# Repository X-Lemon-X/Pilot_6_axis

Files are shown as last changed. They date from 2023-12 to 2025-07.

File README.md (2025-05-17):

# 6 axis remote Controler
- Works over Wi-Fi ( sends constant length ASCI data frame)
- Up to 6 networks saved (with priority from  1 to 6)
- All settings of the Rc can be changed on a configuration website
- Controled inertia of the joysticks and signal values of the joystick coordinates
- Veriable signal refresh rate up to 200Hz
- Auto zero positioning (no more robots moving in slow speed without touching the pilot)
- USB-C charged!
- two 3-DOF joysticks
- 10 buttons (2 of which are on Joy Sticks)
- Integrated LCD
- The RC remembers settings so no need to set it up every time or reprogram it.

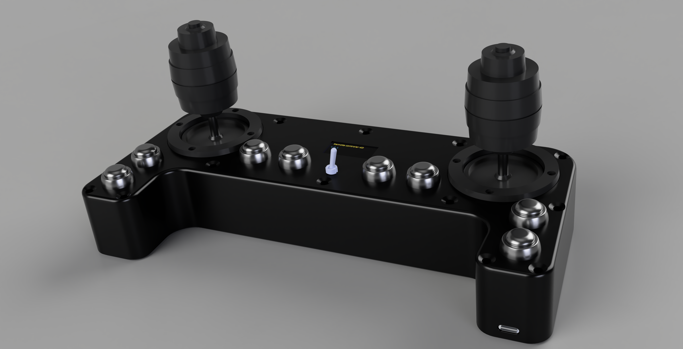
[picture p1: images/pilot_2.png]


## The repo supports demo pc keyboard version of the RC 
 Pc keyboard version for RC without the need for the hardware.
 
 ```bash
  python3 -m venv .venv
  python3 -m pip -r requirements.txt
  source .venv/bin/activate
  python3 pilot_6axis/pilot_6axis/keyboard_rc.py -i IP_ADDRESS -p PORT -f FREQUENCY -v JOYSTICK_VALUE
 ```
for help
```bash
  python3 pilot_6axis/pilot_6axis/keyboard_rc.py
 ```

## To build and run ros package
```bash
  colcon build --packages-select pilot_6axis
  source install/setup.bash 
  ros2 run pilot_6axis rc_node
```

## Data frame
 Consist of 18 elements separated by ':'.
Depending on the settings int_Joystick_(left/right)_(MMin/MMax) value returned by joystick will vary. This setting values should be between -9999<=x<=9999 or 0<=x<=99999 or the data frame length won't be constant, for buttons: 1-pressed 0-not pressed.
```bash
 Example: "$Rc:  340:   200:   12:1:  500:-2045: 2045:1:1:1:0:1:1:0:1:0:#\r"
```

 1. control beginning "$Rc"
 2. joystick_left_x   (5-characters) 
 3. joystick_left_y   (5-characters)
 4. joystick_left_z   (5-characters)
 5. joystick_left_btn  (1-character)
 6. joystick_right_x   (5-characters)
 7. joystick_right_y   (5-characters)
 8. joystick_right_z   (5-characters)
 9. joystick_right_btn  (1-character)
 10. btn_1  (1-character)
 11. btn_2  (1-character)
 12. btn_3  (1-character)
 13. btn_4  (1-character)
 14. btn_5  (1-character)
 15. btn_6  (1-character)
 16. btn_7  (1-character)
 17. btn_8  (1-character)
 18. control end "#\r"

## How to use
### Setup
  1. Enable setup mode by pressing and holding the most centeral button 4 or 5 when turning the Rc On (doesn't matter which one).
  2. Connect to the Rc Wi-Fi network that is displayed on  the LCD.
  3. Open web browser and go to url displayed on the LCD.
  4. Set up the settings of the Rc and press save buttons on the bottom of the page. This will redirect you to the page where you will see if settings were saved. If you made some error it will be shown here.
  5. To leave setup mode shut down the Rc and turn it on again.
  6. Now the Rc will connect to the network with the highest priority that is available. If it can't connect to any of the saved networks it will keep trying to connect to them. If the Rc is connected to the network it will display the IP address on the LCD and show Connected status.
  7. Now setup is done and you can use the Rc.
## Settings list:
#### General Settings
  - **Joystick left MMin** -> minimum value of the left joystick x, y, z axis on the min of the range 
  - **Joystick left MMax** -> maximum value of the left joystick x, y, z axis on the max of the range
  - **Joystick left filer** -> inertia of the left joystick (0-1), the higher inertia the response of the joystick value will be faster.
  - **Joystick right MMin** -> minimum value of the right joystick x, y, z axis on the min of the range
  - **Joystick right MMax** -> maximum value of the right joystick x, y, z axis on the max of the range
  - **Joystick right filer** -> inertia of the right joystick (0-1)
  - **WIFI SSID** => SSID of the wifi network created by the RC in setup mode.
  - **WIFI PASSWORD** => password of the wifi network made by the RC in setup mode
  - **Update frequency** => frequency of sending data frame
  - **Target IP** => IP address to which the RC will send data frame
  - **Host Port** => port to which the RC will send data frame

#### WIFI target networks
  - **Wifi [number 1-6] : Seed** => SSID of the wifi network (where number means priority from 1 to 6)
  - **Wifi [number 1-6] : Password** => Password of the wifi network

## Required component list

### Component Images

  | Component | Photo | Component | Photo |
  |-----------|-------|-----------|-------|
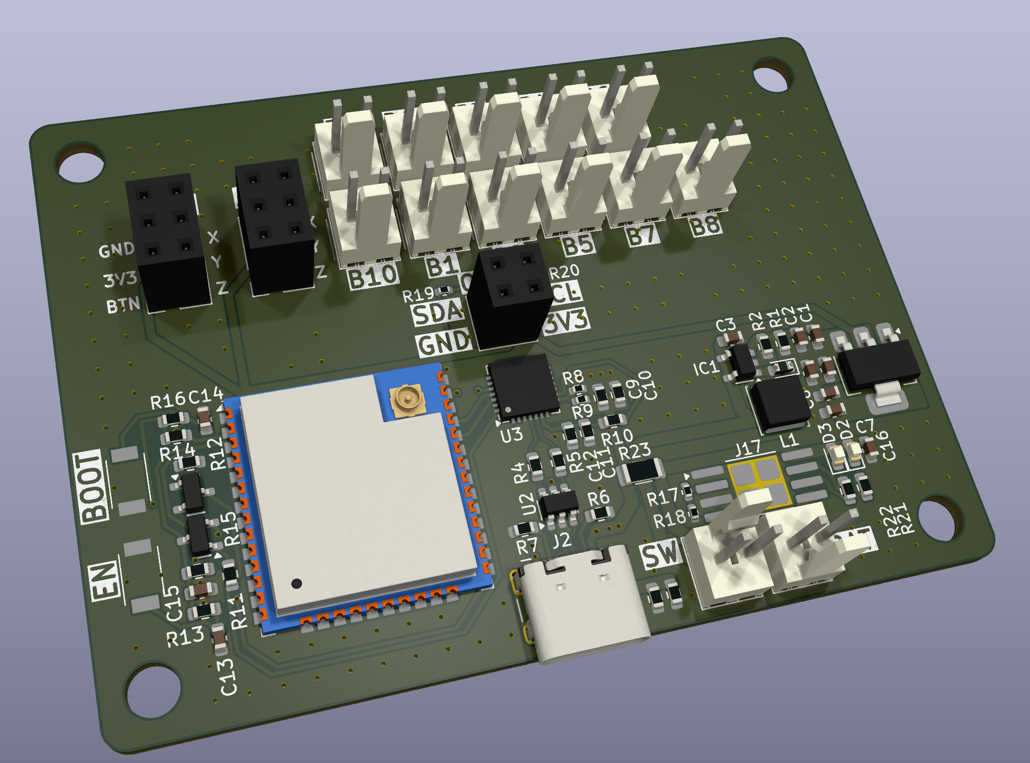
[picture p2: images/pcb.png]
PCB
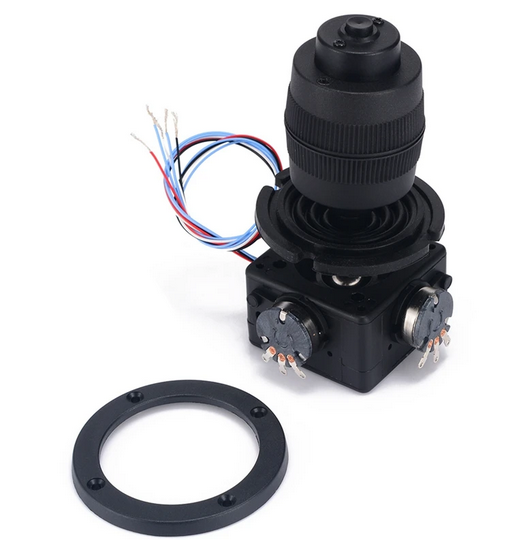
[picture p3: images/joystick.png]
Joystick
  | PCB (order from JLCPCB) |  | Joystick 4-axis JH-D400B-M4 |  |
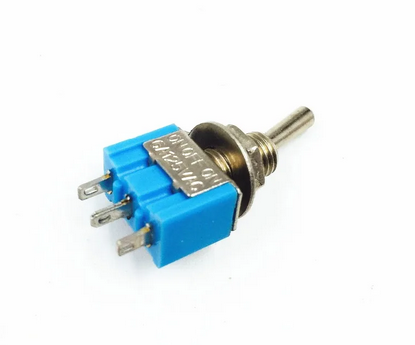
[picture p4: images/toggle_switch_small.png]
Toggle switch
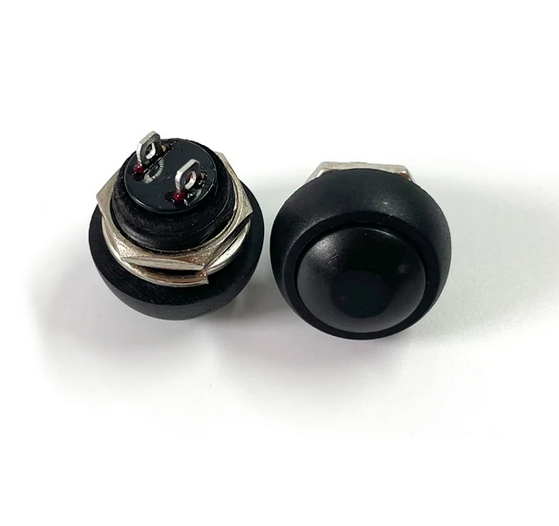
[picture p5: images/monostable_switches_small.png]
Monostable switches
  | Toggle switch 6mm MTS-103 |  | Monostable switches 12mm PBS-33B |  |
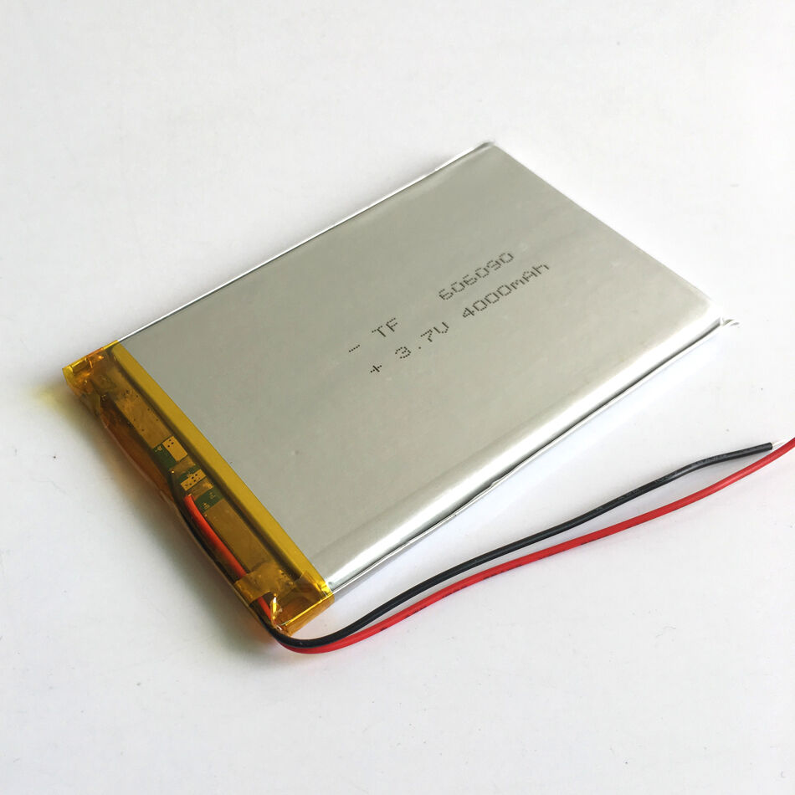
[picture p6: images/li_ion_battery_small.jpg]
Li-ion battery
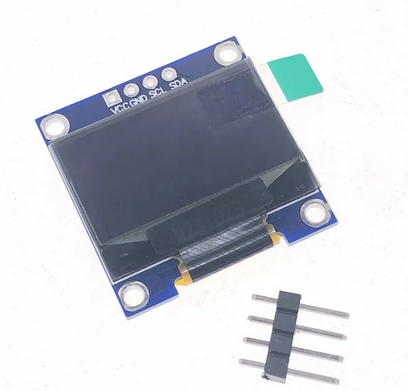
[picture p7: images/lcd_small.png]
LCD
  | Li-ion battery 3.7V 4000mAh |  | LCD 1.3" 128x64 OLED SSD1306 |  |
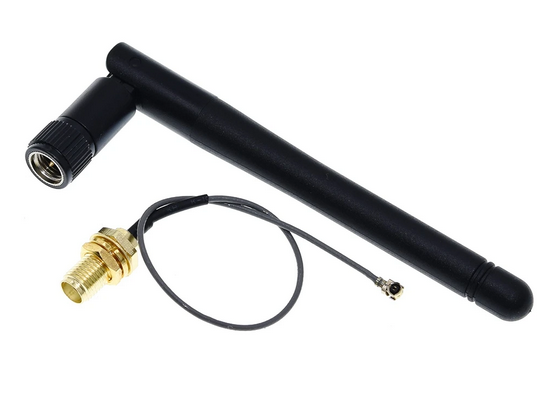
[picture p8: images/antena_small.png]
Antenna
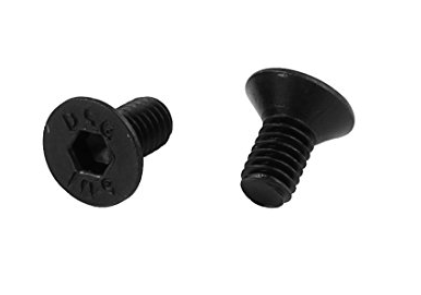
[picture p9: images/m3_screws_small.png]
M3 screws
  | Antena 2.4GHz 3dBi WiFi RP-SMA |  | M3 6mm hex socket flat countersunk |  |
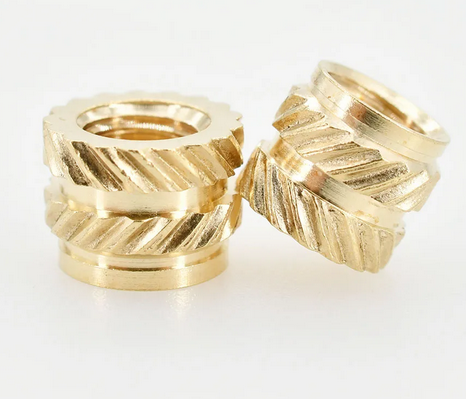
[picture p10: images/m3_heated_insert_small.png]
M3 heated insert
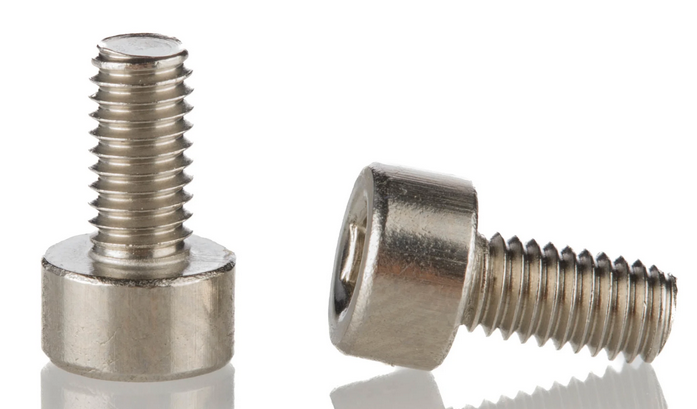
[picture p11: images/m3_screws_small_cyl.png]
M3 screws cylindrical
  | M3 heated insert M3xL3xOD4.2 |  | M3 5mm hex socket cylindrical |  |

### Component list 

  | Component Name                                   | Parts Count | Description                                              |
  |--------------------------------------------------|-------------|----------------------------------------------------------|
  | Joystick 4-axis JH-D400B-M4                      | 2           | 3-DOF joysticks for axis control                        |
  | Toggle switch 6mm MTS-103                        | 1           | Main toggle switch for power or mode selection           |
  | Monostable switches 12mm PBS-33B                 | 8           | Momentary push buttons for user input                   |
  | Li-ion battery 606090 3.7V 4000mAh               | 1           | Rechargeable battery for power supply                    |
  | LCD 1.3" 128x64 OLED SSD1306                     | 1           | Display for status and configuration                     |
  | Antena 2.4GHz 3dB WiFi 2.4GHz RP-SMA             | 1           | External Wi-Fi antenna for wireless communication        |
  | M3 6mm hex socket flat countersunk screws        | 14          | Screws for assembling the enclosure                      |
  | M3 heated insert M3xL3xOD4.2                     | 19          | Threaded inserts for secure screw mounting               |
  | M3 5mm hex socket cylindrical screws             | 4           | Additional screws for assembly                           |
  | PCB (order from JLCPCB)                          | 1           | Main circuit board for the controller                    |
  | BOM Components (see BOM file)                    | -           | All other electronic components (resistors, ICs, etc.)   |

- BOM file "Electric schematic/Pilot6Axis/jlcpcb/production_files/BOM-Pilot6Axis.csv"
- JLCB gerber files "Electric schematic/Pilot6Axis/jlcpcb/production_files/GERBER-Pilot6Axis.zip"

## How to assembly
  You figure it out.

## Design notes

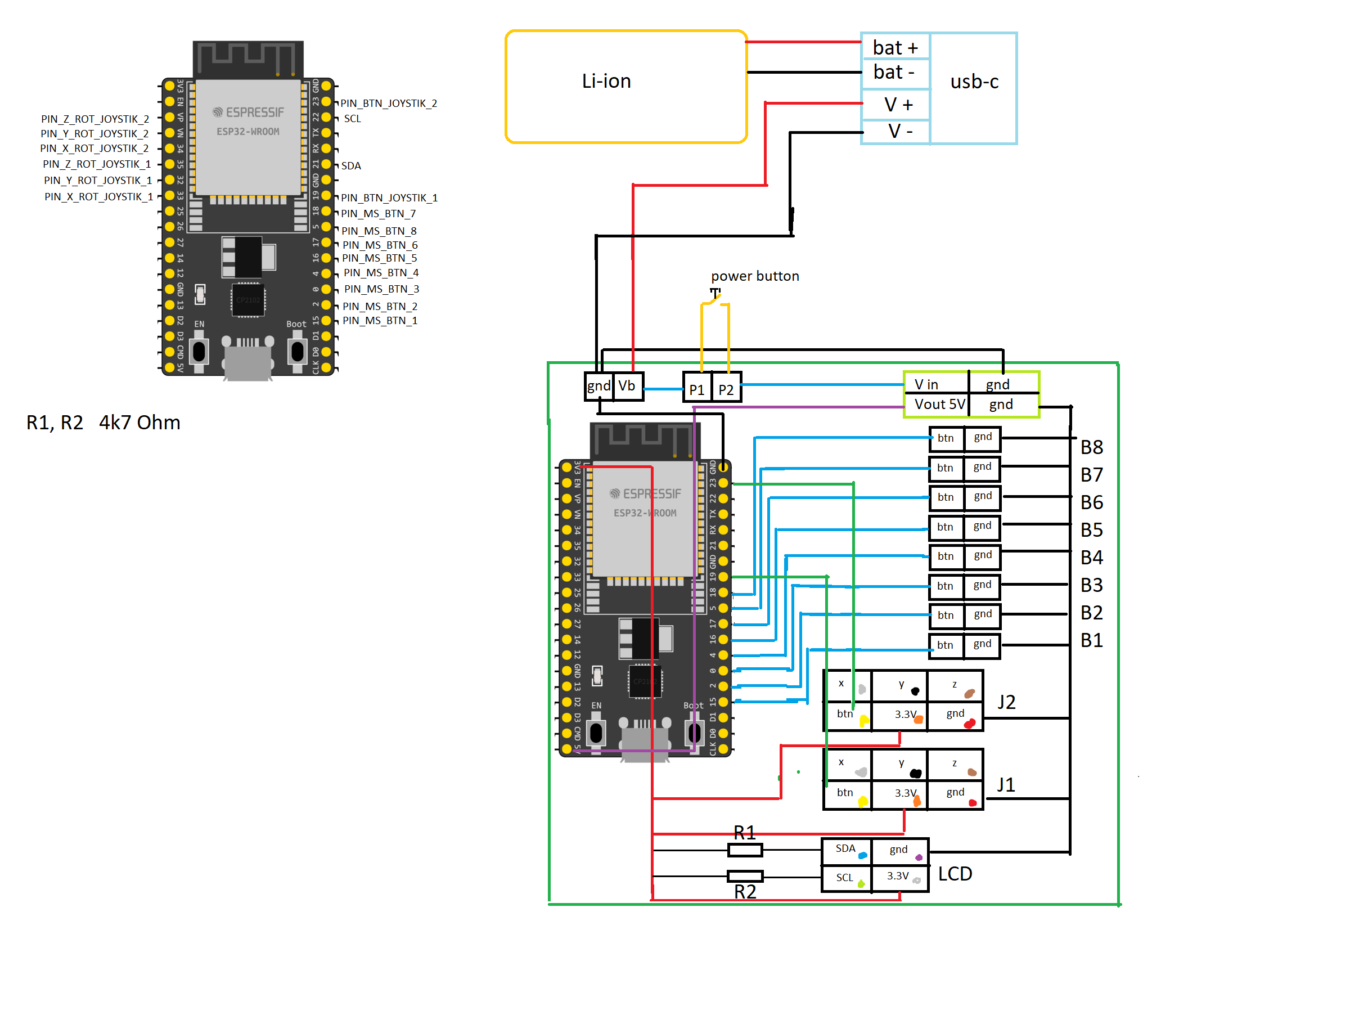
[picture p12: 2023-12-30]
Electric schematic/Pilot 6 axis electronic schematic.png

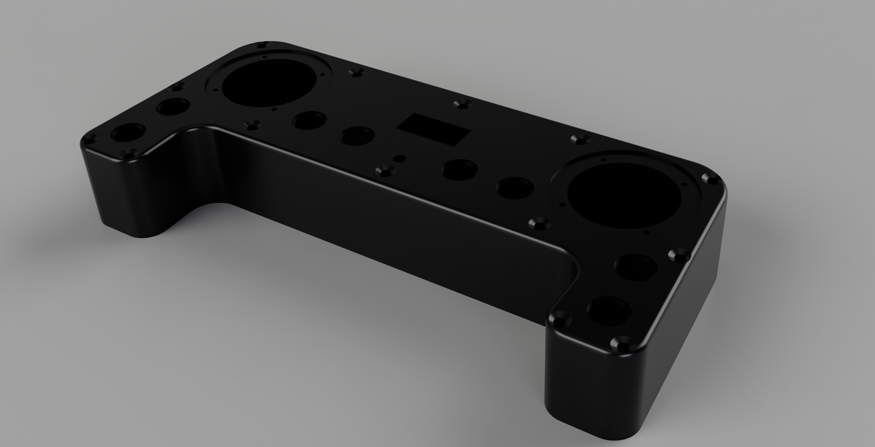
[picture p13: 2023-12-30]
images/pilot_1.png

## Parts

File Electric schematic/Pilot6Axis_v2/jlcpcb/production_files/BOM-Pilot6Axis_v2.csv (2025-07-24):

Comment | Designator | Footprint | LCSC | Quantity
10uH | L1 | L_Cenker_CKCS4018 | C1035 | 1
40.5k | R2 | R_0603_1608Metric | C12447 | 1
100n | C10,C11,C17,C18,C19,C22,C25,C26,C3,C34,C43,C45,C46,C7 | R_0603_1608Metric | C14663 | 14
1k | R10 | R_0603_1608Metric | C14676 | 1
1nF | C13,C14,C35,C36,C47,C5,C6 | C_0603_1608Metric | C1588 | 7
220pF | C23,C24,C4 | C_0603_1608Metric | C1603 | 3
47nF | C27,C28 | C_0603 | C1622 | 2
4.7uF | C1,C16,C39 | C_0603_1608Metric | C19666 | 3
10u | C12,C44,C9 | R_0603_1608Metric | C19702 | 3
S9014 | Q1,Q2 | Q_SOT-23 | C20069130 | 2
AO3400A | Q3,Q4 | Q_SOT-23 | C20917 | 2
1kΩ | R13,R14,R25,R28,R30,R31,R32 | R_0603 | C21190 | 7
100Ω | R26 | R_0603 | C22775 | 1
Red | D2,D3,D4,D5,D6,D7,D8 | D_0603 | C2286 | 7
30kΩ | R22 | R_0603 | C22984 | 1
330Ω | R4 | R_0603 | C23138 | 1
4.7kΩ | R19,R20 | R_0603 | C23162 | 2
22Ω | R29 | R_0603 | C23345 | 1
100kΩ | R1,R24 | R_0603 | C25803 | 2
5.1kΩ | R21 | R_0402 | C25905 | 1
13.3k | R11,R12,R15,R16,R17,R18,R3,R8,R9 | R_0603_1608Metric | C25952 | 9
USB_C_Receptacle_USB2.0_16P | J3 | USB_C_Receptacle_HCTL_HC-TYPE-C-16P-01A | C2765186 | 1
MBR0520 | D1 | D_0603_1608Metric | C2858712 | 1
LM27313XMFX_NOPB | IC1 | SOT-23-5 | C341750 | 1
3kΩ | R27 | R_0603 | C4211 | 1
33k | R5 | R_0603_1608Metric | C4216 | 1
USBLC6-2SC6 | U2 | SOT-23-6 | C5180249 | 1
10nF | C8 | R_0603_1608Metric | C57112 | 1
AMS1117-3.3 | U1 | SOT-223-3_TabPin2 | C6186 | 1
22R | R6,R7 | R_0603_1608Metric | C71618 | 2
10uF | C15,C2,C20,C21,C29,C30,C31,C32,C33,C37,C38,C40,C41,C42 | C_0603 | C96446 | 14
CP2102N-Axx-xQFN28 | U3 | QFN-28-1EP_5x5mm_P0.5mm_EP3.35x3.35mm | C964632 | 1
127k | R23 | R_0603_1608Metric |  | 1
Conn_01x06 | J9 | JST_PH_B6B-PH-K_1x06_P2.00mm_Vertical |  | 1
TPS25751SRSMR | IC2 | QFN40P400X400X100-33N-D |  | 1
SolderJumper_2_Bridged | JP1 | SolderJumper-2_P1.3mm_Open_TrianglePad1.0x1.5mm |  | 1
Conn_01x12 | J8 | JST_PH_B12B-PH-K_1x12_P2.00mm_Vertical |  | 1
Conn_01x06 | J4 | JST_PH_B6B-PH-K_1x06_P2.00mm_Vertical |  | 1
MCP23017_ML | U14 | QFN-28-1EP_6x6mm_P0.65mm_EP4.25x4.25mm |  | 1
10k | TH1 | PinHeader_1x02_P2.54mm_Vertical |  | 1
TPS3422EGDRYR | IC4 | DRY_R-PUSON-N6_ |  | 1
SN74LVC1G74RSE2 | IC5 | SN74LVC1G74RSE2 |  | 1
BQ25792RQMR | IC3 | BQ25792RQMR |  | 1
1u | L2 | L_APV_APH0420 |  | 1
ESP32-WROOM-32U | U4 | ESP32-WROOM-32U |  | 1
Battery input | J1 | JST_PH_B2B-PH-K_1x02_P2.00mm_Vertical |  | 1
Conn_01x06 | J10 | JST_PH_B6B-PH-K_1x06_P2.00mm_Vertical |  | 1
Oled | J6 | PinSocket_2x02_P2.54mm_Vertical |  | 1
~ | U12 | ts-1212f |  | 1
~ | U7 | ts-1212f |  | 1
~ | U9 | ts-1212f |  | 1
Power switch | U18 | ts-1212f |  | 1
~ | U6 | ts-1212f |  | 1
~ | U10 | ts-1212f |  | 1
~ | U11 | ts-1212f |  | 1
~ | U8 | ts-1212f |  | 1
~ | U15 | ts-1212f |  | 1
~ | U13 | ts-1212f |  | 1
~ | U16 | ts-1212f |  | 1
~ | U5 | ts-1212f |  | 1
CAT24C512WI-GT3 | U17 | SOIC-8_3.9x4.9mm_P1.27mm |  | 1

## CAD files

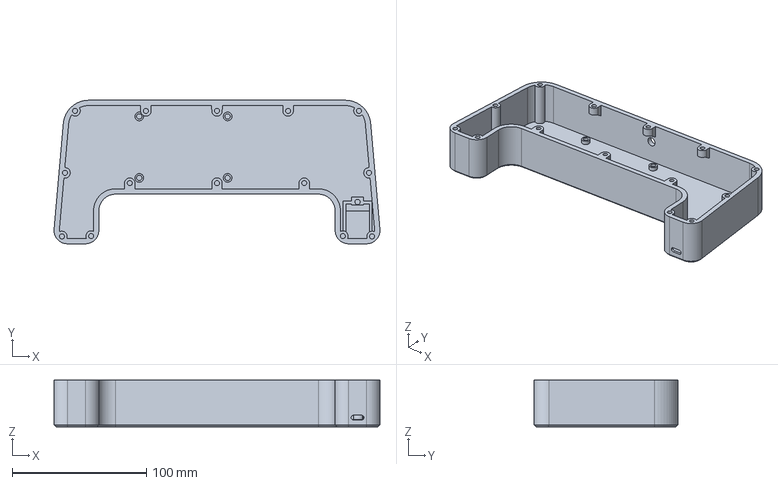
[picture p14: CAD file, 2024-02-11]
3D_Files/Pilot6axisV2.step
242.9 x 107.0 x 35.0 mm

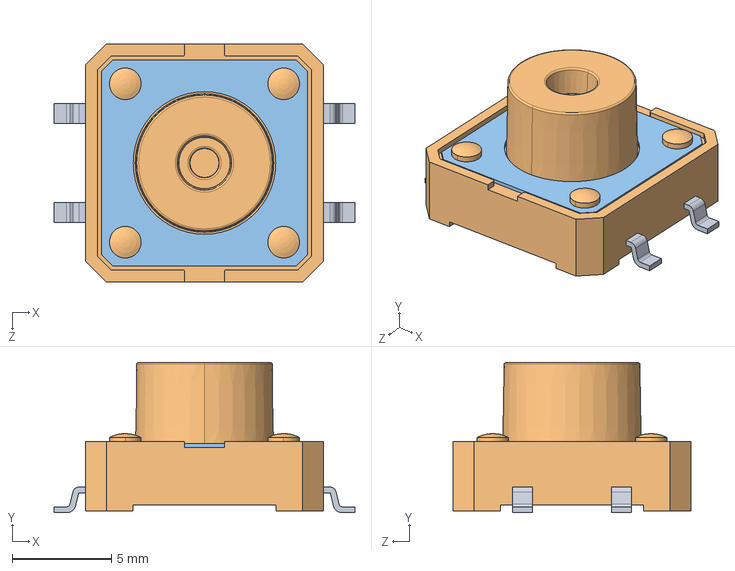
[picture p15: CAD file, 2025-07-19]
Electric schematic/Pilot6Axis_v2/parts/Same_Sky_TS16-1212-75-BK-160-SMT-TR.step
15.2 x 7.60 x 12.0 mm

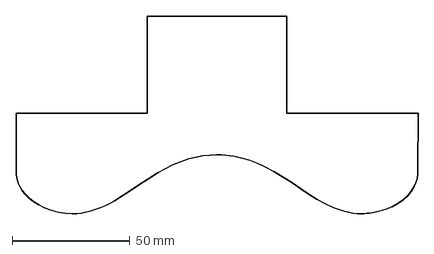
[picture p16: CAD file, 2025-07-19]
Electric schematic/Pilot6Axis_v2/pilot6axis_edge_cuts.dxf
171.0 x 83.9 mm

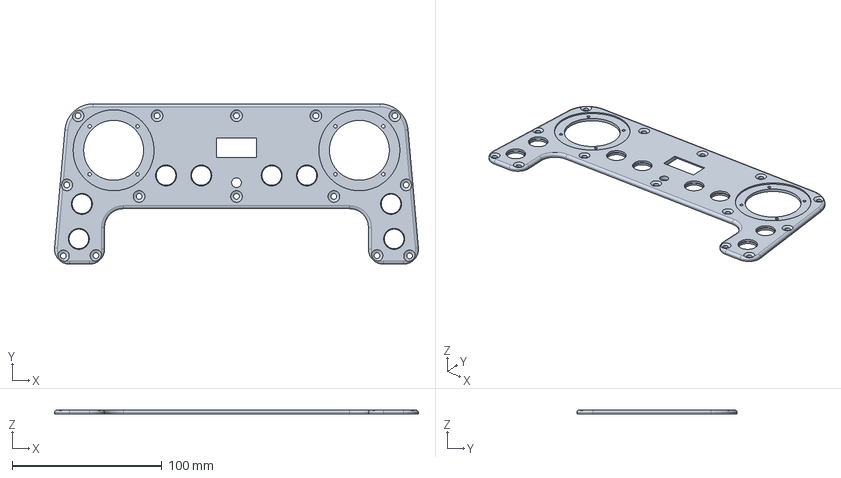
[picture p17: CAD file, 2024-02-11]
3D_Files/TopCover.step
242.9 x 107.0 x 3.00 mm

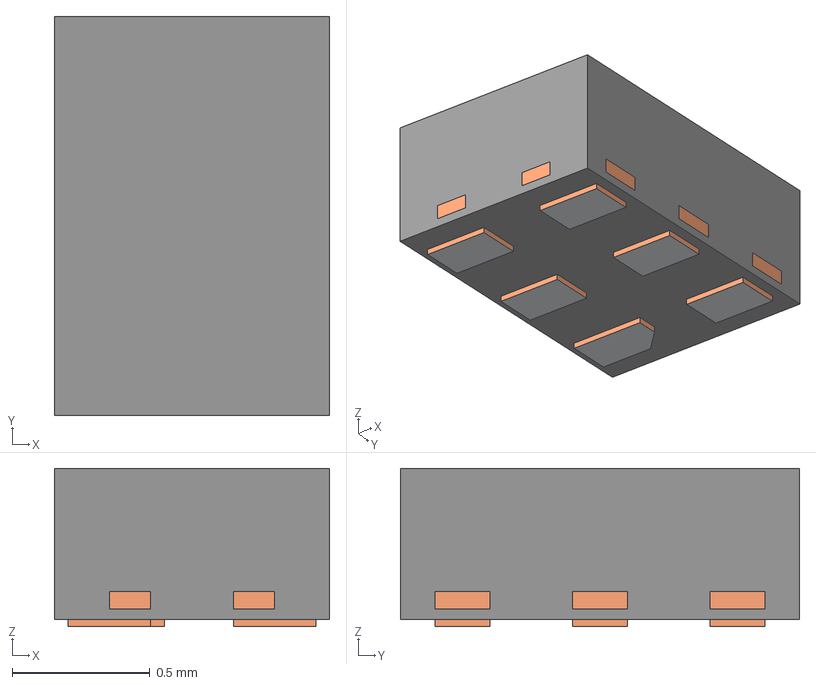
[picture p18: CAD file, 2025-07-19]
Electric schematic/Pilot6Axis_v2/parts/TPS3422EGDRYR.stp
1.00 x 1.45 x 0.575 mm
BODY-SON
FRAME-DRY0006A
PIN1-ID

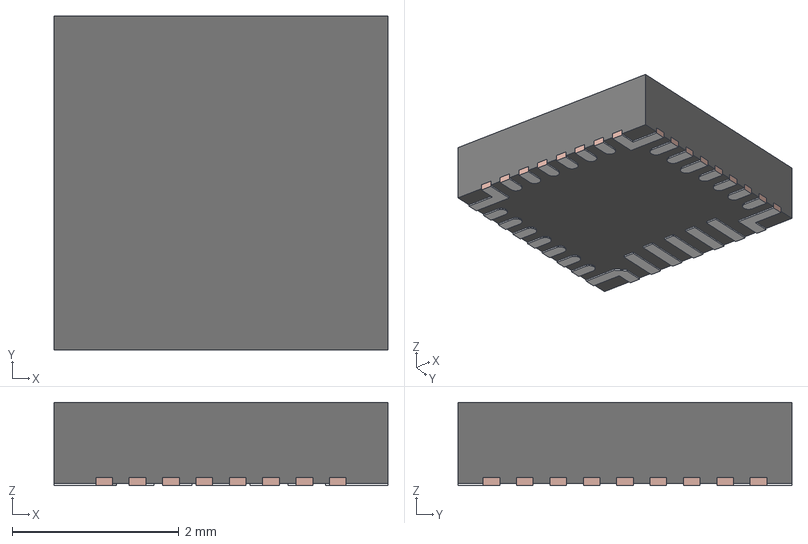
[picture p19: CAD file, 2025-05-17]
Electric schematic/Pilot6Axis_v2/parts/BQ25792RQMR.stp
4.00 x 4.00 x 1.00 mm
FRAME
MOLD

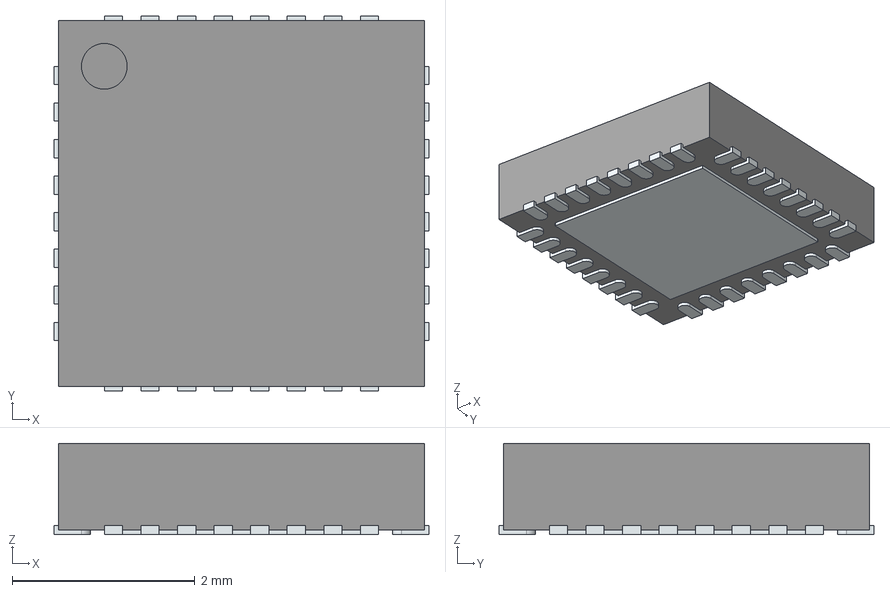
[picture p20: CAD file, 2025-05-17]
Electric schematic/Pilot6Axis_v2/parts/TPS25751SRSMR.stp
4.10 x 4.10 x 1.00 mm
ThermalPin
PinsArrayLR
PinsArrayTB

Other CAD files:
3D_Files/Pilot6axisV2.3mf
3D_Files/TopCover.3mf

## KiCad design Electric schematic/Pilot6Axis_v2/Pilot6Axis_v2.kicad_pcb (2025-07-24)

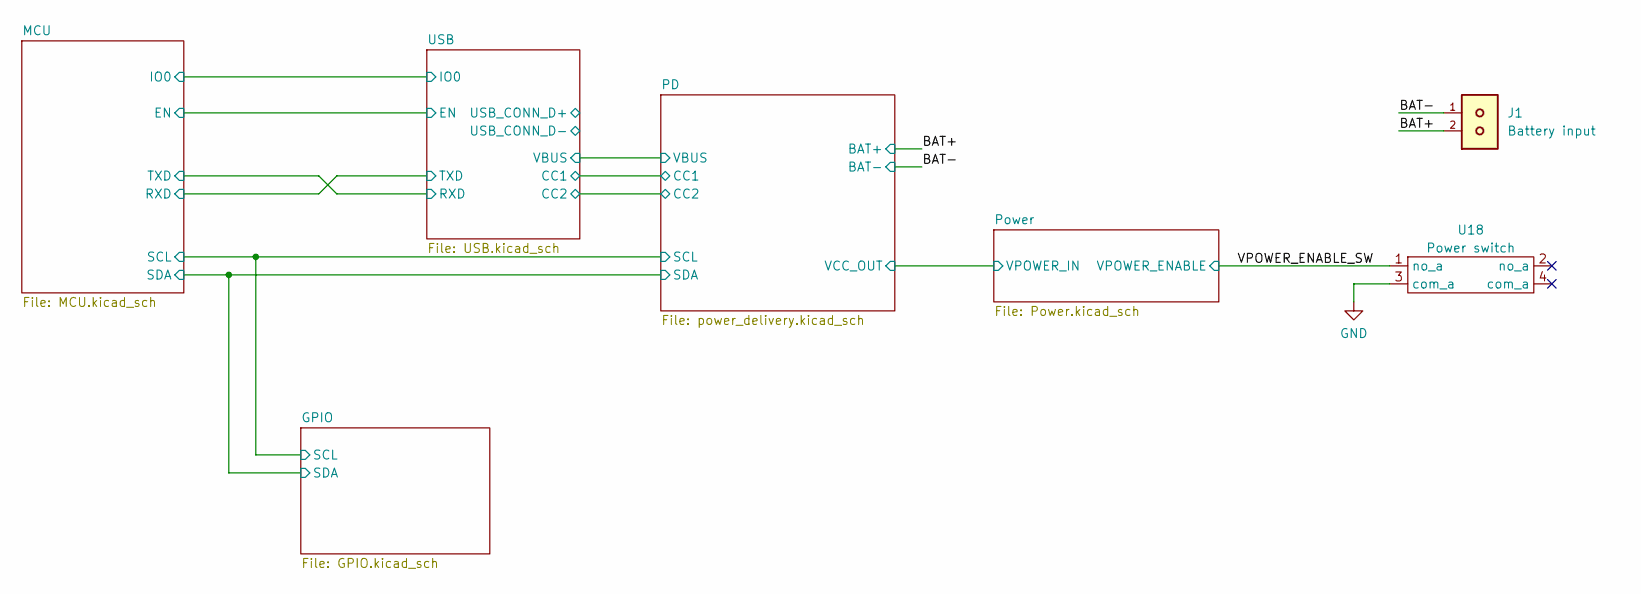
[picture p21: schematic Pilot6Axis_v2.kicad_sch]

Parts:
J1: Battery input; JST_PH_B2B-PH-K_1x02_P2.00mm_Vertical
U18: Power switch; ts-1212f

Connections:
/BAT+: J1.2; also elsewhere on the board
/VPOWER_ENABLE_SW: U18.1 (no_a); also elsewhere on the board
GND: J1.1, U18.3 (com_a); also elsewhere on the board

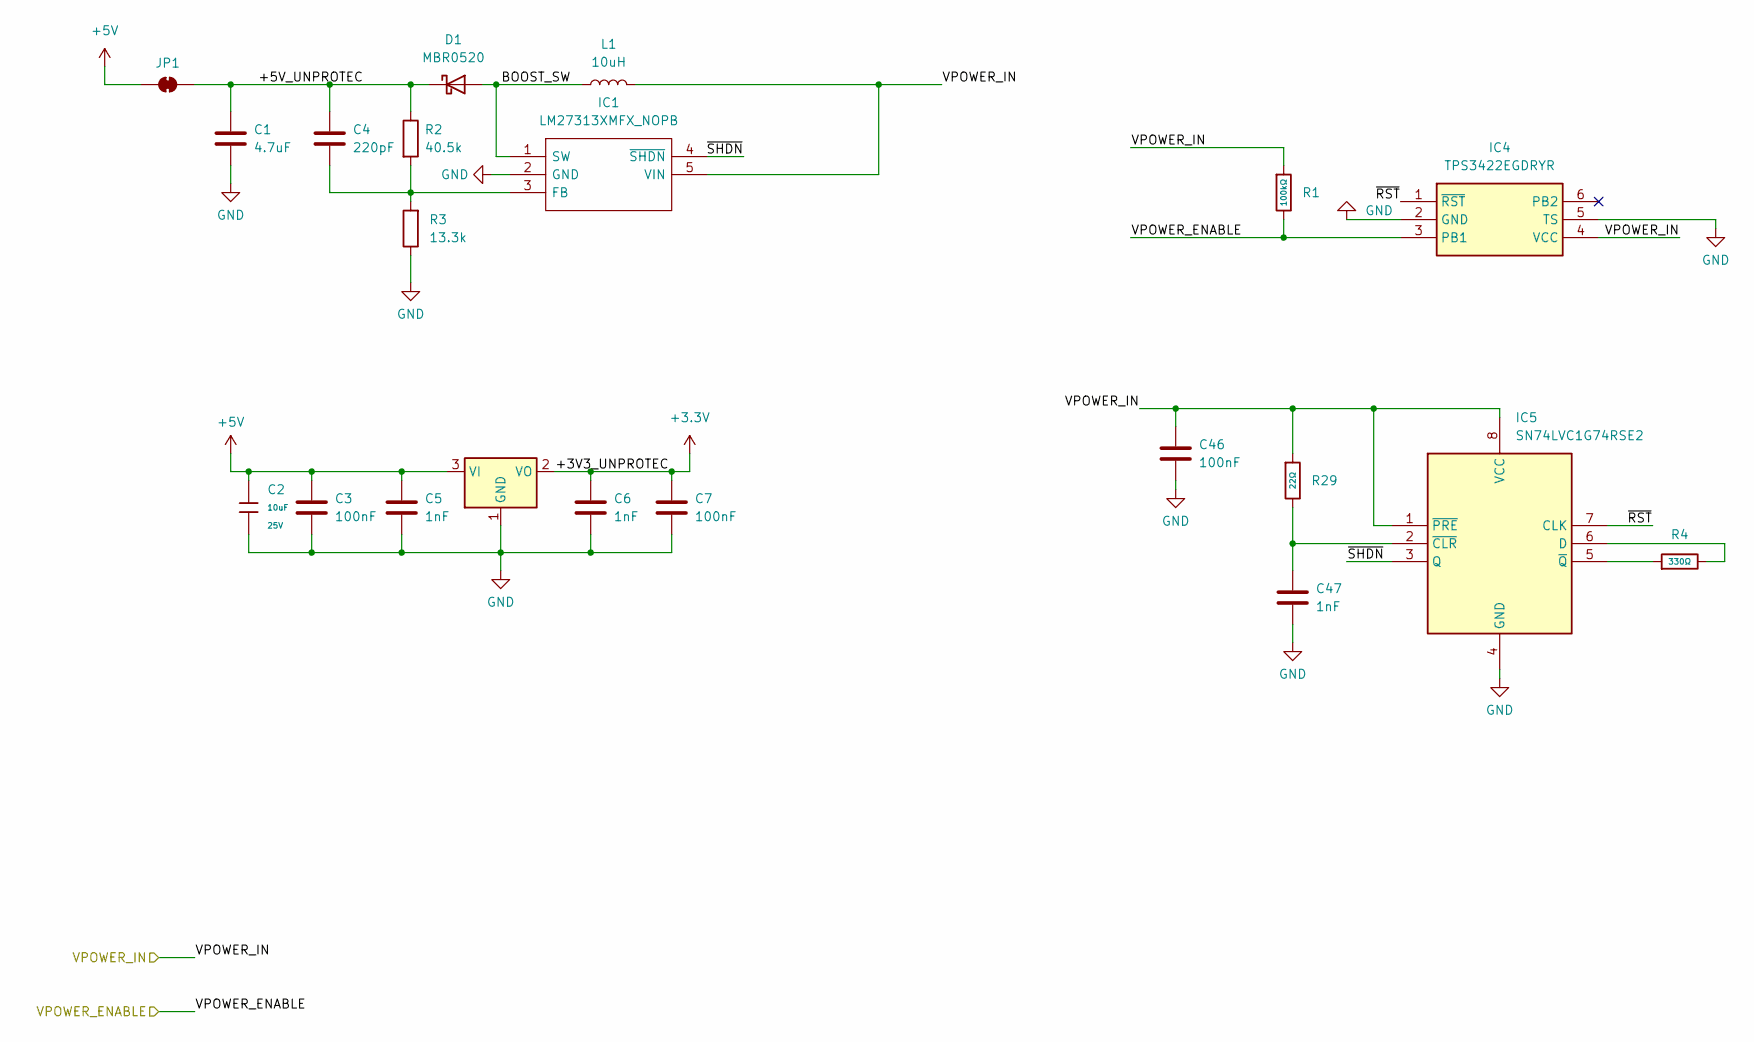
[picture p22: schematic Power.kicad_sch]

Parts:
C1: 4.7uF; C_0603_1608Metric; LCSC C19666
C2: 10uF; C_0603; Voltage Rated 25V; Tolerance ±20%; Part CL10A106MA8NRNC; LCSC C96446
C3, C7, C46: 100nF; C_0603_1608Metric; LCSC C14663
C4: 220pF; C_0603_1608Metric; LCSC C1603
C5, C6, C47: 1nF; C_0603_1608Metric; LCSC C1588
D1: MBR0520; D_0603_1608Metric; LCSC C2858712
IC1: LM27313XMFX_NOPB; SOT-23-5; Manufacturer_Part_Number LM27313XMFX/NOPB; Mouser Part Number 926-LM27313XMFX/NOPB
IC4: TPS3422EGDRYR; DRY_R-PUSON-N6_; Manufacturer_Part_Number TPS3422EGDRYR; Mouser Part Number 595-TPS3422EGDRYR
IC5: SN74LVC1G74RSE2; Manufacturer_Part_Number SN74LVC1G74RSE2; Mouser Part Number 595-SN74LVC1G74RSE2
JP1: SolderJumper_2_Bridged; SolderJumper-2_P1.3mm_Open_TrianglePad1.0x1.5mm
L1: 10uH; L_Cenker_CKCS4018; LCSC C1035
R1: 100kΩ; R_0603; Overload Voltage (Max) 75V; Tolerance ±1%; Part 0603WAF1003T5E; LCSC C25803
R2: 40.5k; R_0603_1608Metric; LCSC C12447
R3: 13.3k; R_0603_1608Metric; LCSC C25952
R4: 330Ω; R_0603; Overload Voltage (Max) 75V; Tolerance ±1%; Part 0603WAF3300T5E; LCSC C23138
R29: 22Ω; R_0603; Overload Voltage (Max) 75V; Tolerance ±1%; Part 0603WAF220JT5E; LCSC C23345
U1: AMS1117-3.3; SOT-223-3_TabPin2; LCSC C6186

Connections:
+3.3V: C6.1, C7.1, U1.2 (VO); also elsewhere on the board
+5V: C2.1, C3.1, C5.1, JP1.1 (A), U1.3 (VI); also elsewhere on the board
/PD/VCC_OUT: C46.1, IC1.5 (VIN), IC4.4 (VCC), IC5.1 (~PRE), IC5.8 (VCC), L1.2, R1.1, R29.1; also elsewhere on the board
/Power/+5V_UNPROTEC: C1.1, C4.2, D1.1 (K), JP1.2 (B), R2.1
/Power/BOOST_SW: D1.2 (A), IC1.1 (SW), L1.1
/Power/~RST: IC4.1 (~RST), IC5.7 (CLK)
/Power/~SHDN: IC1.4 (~SHDN), IC5.3 (Q)
/VPOWER_ENABLE_SW: IC4.3 (PB1), R1.2; also elsewhere on the board
GND: C1.2, C2.2, C3.2, C5.2, C6.2, C7.2, C46.2, C47.2, IC1.2 (GND), IC4.2 (GND), IC4.5 (TS), IC5.4 (GND), R3.1, U1.1 (GND); also elsewhere on the board
unnamed: C4.1, IC1.3 (FB), R2.2, R3.2
unnamed: IC5.6 (D), R4.2
unnamed: C47.1, IC5.2 (~CLR), R29.2
unnamed: IC5.5 (~Q), R4.1

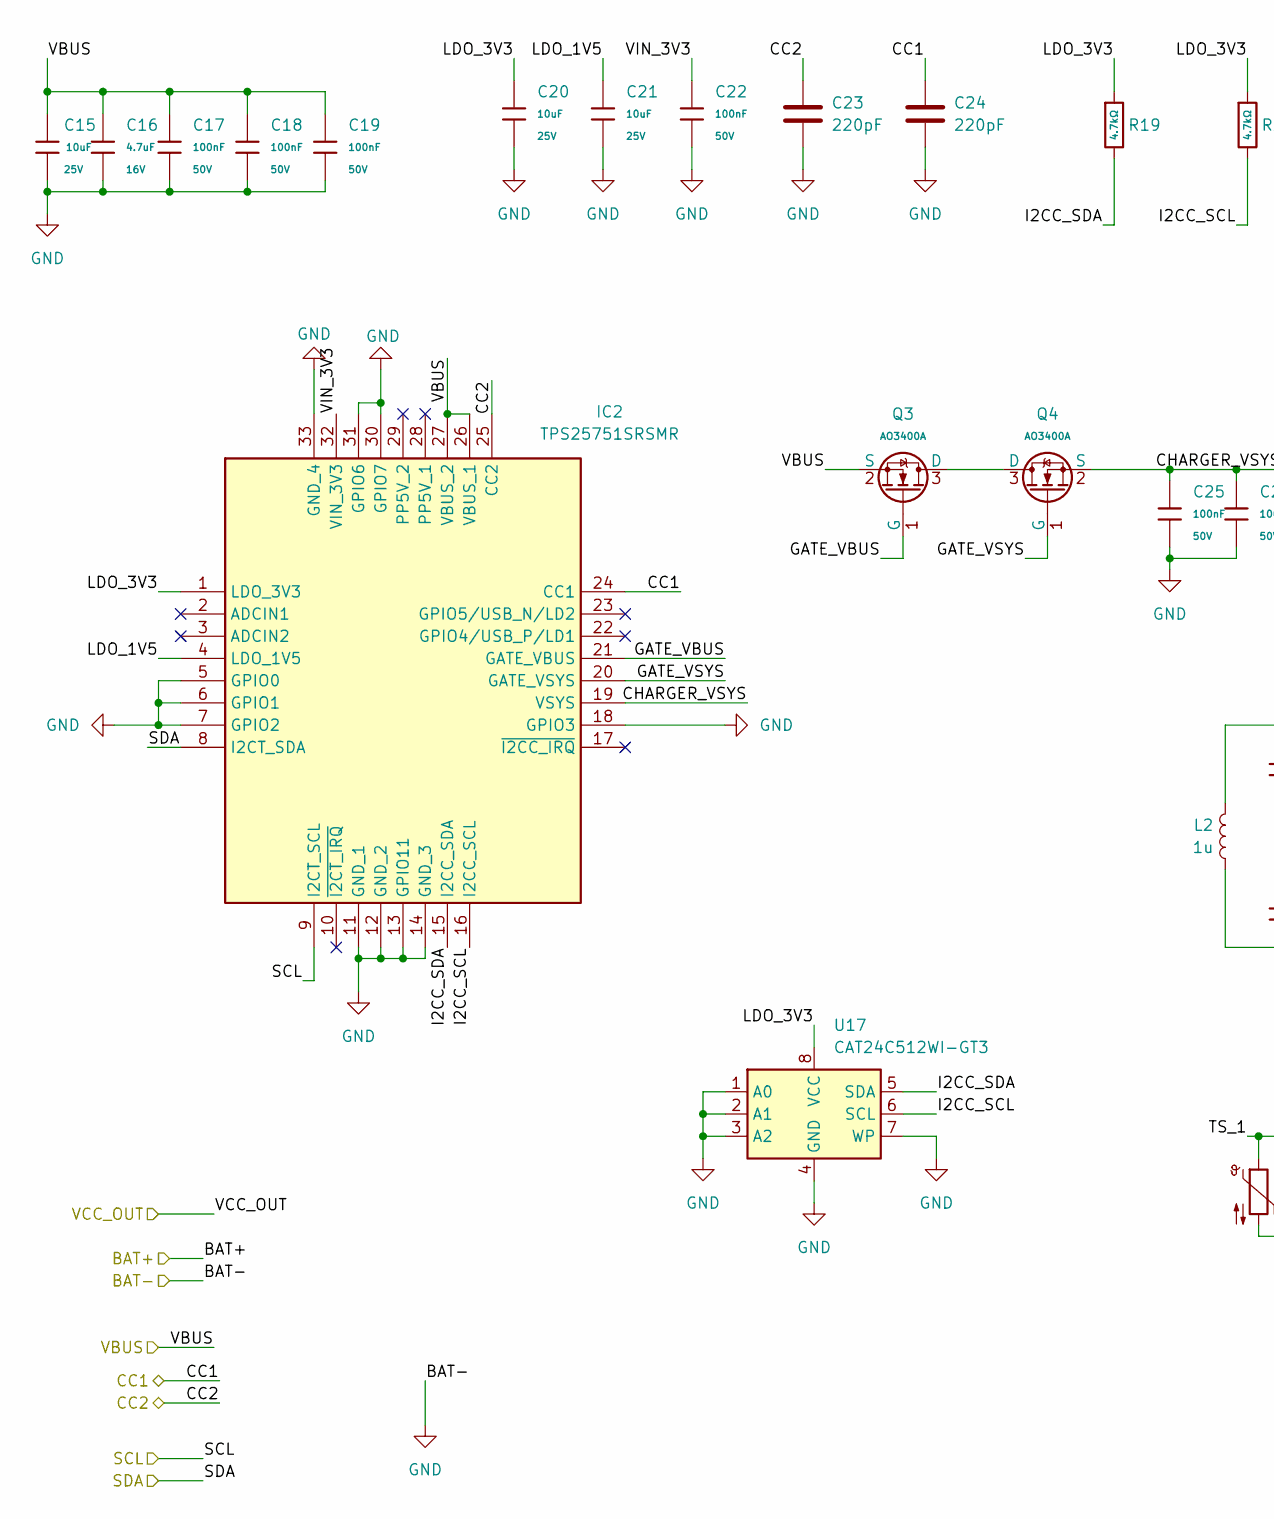
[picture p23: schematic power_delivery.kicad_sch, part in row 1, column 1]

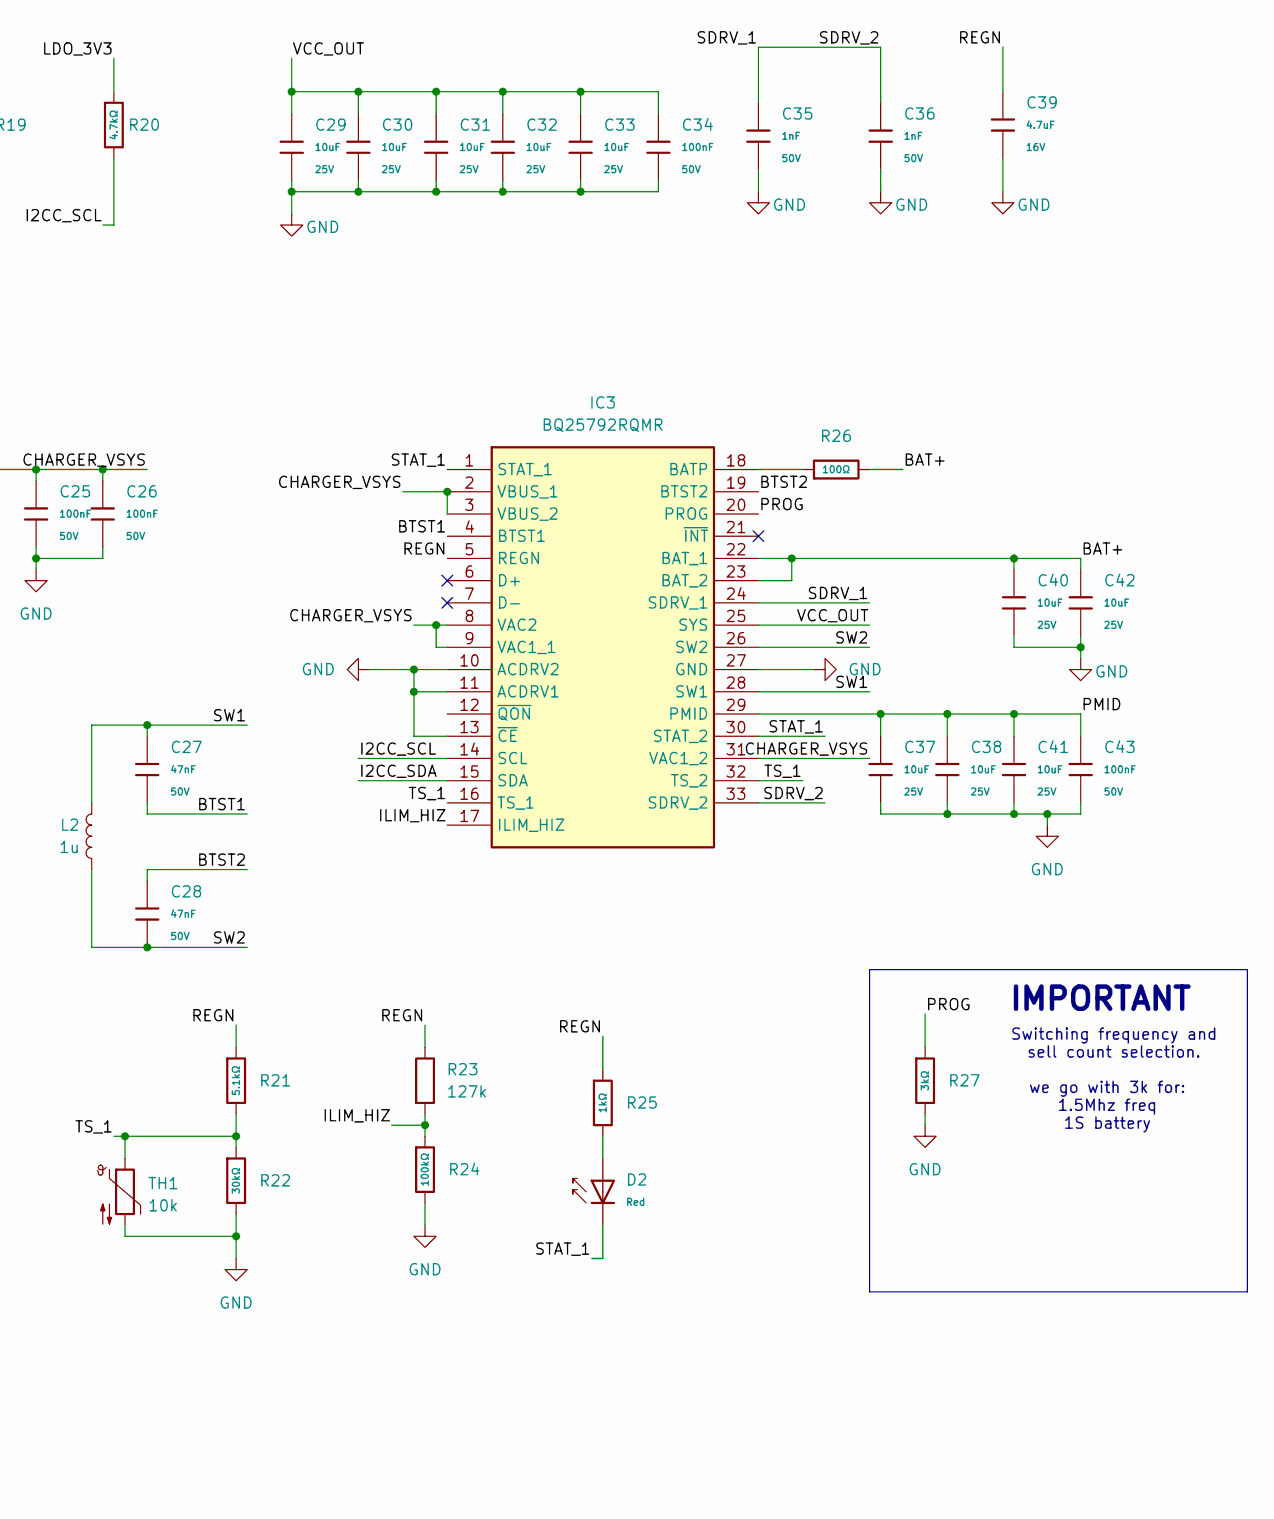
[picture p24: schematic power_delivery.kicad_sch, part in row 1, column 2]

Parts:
C15, C20, C21, C29, C30, C31, C32, C33, C37, C38, C40, C41, C42: 10uF; C_0603; Voltage Rated 25V; Tolerance ±20%; Part CL10A106MA8NRNC; LCSC C96446
C16, C39: 4.7uF; C_0603; Voltage Rated 16V; Tolerance ±10%; Part CL10A475KO8NNNC; LCSC C19666
C17, C18, C19, C22, C25, C26, C34, C43: 100nF; C_0603; Voltage Rated 50V; Tolerance ±10%; Part CC0603KRX7R9BB104; LCSC C14663
C23, C24: 220pF; C_0603_1608Metric; LCSC C1603
C27, C28: 47nF; C_0603; Voltage Rated 50V; Tolerance ±10%; Part CL10B473KB8NNNC; LCSC C1622
C35, C36: 1nF; C_0603; Voltage Rated 50V; Tolerance ±10%; Part CL10B102KB8NNNC; LCSC C1588
D2: Red; D_0603; Part KT-0603R; LCSC C2286
IC2: TPS25751SRSMR; QFN40P400X400X100-33N-D; Manufacturer_Part_Number TPS25751SRSMR; Mouser Part Number 595-TPS25751SRSMR
IC3: BQ25792RQMR; Manufacturer_Part_Number BQ25792RQMR; Mouser Part Number 595-BQ25792RQMR
L2: 1u; L_APV_APH0420
Q3, Q4: AO3400A; Q_SOT-23; Part AO3400A; LCSC C20917
R19, R20: 4.7kΩ; R_0603; Overload Voltage (Max) 75V; Tolerance ±1%; Part 0603WAF4701T5E; LCSC C23162
R21: 5.1kΩ; R_0402; Overload Voltage (Max) 50V; Tolerance ±1%; Part 0402WGF5101TCE; LCSC C25905
R22: 30kΩ; R_0603; Overload Voltage (Max) 75V; Tolerance ±1%; Part 0603WAF3002T5E; LCSC C22984
R23: 127k; R_0603_1608Metric
R24: 100kΩ; R_0603; Overload Voltage (Max) 75V; Tolerance ±1%; Part 0603WAF1003T5E; LCSC C25803
R25: 1kΩ; R_0603; Overload Voltage (Max) 75V; Tolerance ±1%; Part 0603WAF1001T5E; LCSC C21190
R26: 100Ω; R_0603; Overload Voltage (Max) 75V; Tolerance ±1%; Part 0603WAF1000T5E; LCSC C22775
R27: 3kΩ; R_0603; Overload Voltage (Max) 75V; Tolerance ±1%; Part 0603WAF3001T5E; LCSC C4211
TH1: 10k; PinHeader_1x02_P2.54mm_Vertical
U17: CAT24C512WI-GT3; SOIC-8_3.9x4.9mm_P1.27mm

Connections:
/BAT+: C40.1, C42.1, IC3.22 (BAT_1), IC3.23 (BAT_2), R26.2; also elsewhere on the board
/GPIO/SCL: IC2.9 (I2CT_SCL); also elsewhere on the board
/GPIO/SDA: IC2.8 (I2CT_SDA); also elsewhere on the board
/PD/BTST1: C27.2, IC3.4 (BTST1)
/PD/BTST2: C28.1, IC3.19 (BTST2)
/PD/CC1: C24.2, IC2.24 (CC1); also elsewhere on the board
/PD/CC2: C23.2, IC2.25 (CC2); also elsewhere on the board
/PD/CHARGER_VSYS: C25.1, C26.1, IC2.19 (VSYS), IC3.2 (VBUS_1), IC3.3 (VBUS_2), IC3.8 (VAC2), IC3.9 (VAC1_1), IC3.31 (VAC1_2), Q4.2 (S)
/PD/GATE_VBUS: IC2.21 (GATE_VBUS), Q3.1 (G)
/PD/GATE_VSYS: IC2.20 (GATE_VSYS), Q4.1 (G)
/PD/I2CC_SCL: IC2.16 (I2CC_SCL), IC3.14 (SCL), R20.2, U17.6 (SCL)
/PD/I2CC_SDA: IC2.15 (I2CC_SDA), IC3.15 (SDA), R19.2, U17.5 (SDA)
/PD/ILIM_HIZ: IC3.17 (ILIM_HIZ), R23.2, R24.1
/PD/LDO_1V5: C21.1, IC2.4 (LDO_1V5)
/PD/LDO_3V3: C20.1, IC2.1 (LDO_3V3), R19.1, R20.1, U17.8 (VCC)
/PD/PMID: C37.1, C38.1, C41.1, C43.1, IC3.29 (PMID)
/PD/PROG: IC3.20 (PROG), R27.1
/PD/REGN: C39.1, IC3.5 (REGN), R21.1, R23.1, R25.1
/PD/SDRV_1: C35.1, C36.1, IC3.24 (SDRV_1), IC3.33 (SDRV_2)
/PD/STAT_1: D2.1, IC3.1 (STAT_1), IC3.30 (STAT_2)
/PD/SW1: C27.1, IC3.28 (SW1), L2.1
/PD/SW2: C28.2, IC3.26 (SW2), L2.2
/PD/TS_1: IC3.16 (TS_1), IC3.32 (TS_2), R21.2, R22.1, TH1.1
/PD/VBUS: C15.1, C16.1, C17.1, C18.1, C19.1, IC2.26 (VBUS_1), IC2.27 (VBUS_2), Q3.2 (S); also elsewhere on the board
/PD/VCC_OUT: C29.1, C30.1, C31.1, C32.1, C33.1, C34.1, IC3.25 (SYS); also elsewhere on the board
/PD/VIN_3V3: C22.1, IC2.32 (VIN_3V3)
GND: C15.2, C16.2, C17.2, C18.2, C19.2, C20.2, C21.2, C22.2, C23.1, C24.1, C25.2, C26.2, C29.2, C30.2, C31.2, C32.2, C33.2, C34.2, C35.2, C36.2, C37.2, C38.2, C39.2, C40.2, C41.2, C42.2, C43.2, IC2.5 (GPIO0), IC2.6 (GPIO1), IC2.7 (GPIO2), IC2.11 (GND_1), IC2.12 (GND_2), IC2.13 (GPIO11), IC2.14 (GND_3), IC2.18 (GPIO3), IC2.30 (GPIO7), IC2.31 (GPIO6), IC2.33 (GND_4), IC3.10 (ACDRV2), IC3.11 (ACDRV1), IC3.13 (~CE), IC3.27 (GND), R22.2, R24.2, R27.2, TH1.2, U17.1 (A0), U17.2 (A1), U17.3 (A2), U17.4 (GND), U17.7 (WP); also elsewhere on the board
unnamed: D2.2, R25.2
unnamed: IC3.18 (BATP), R26.1
unnamed: Q3.3 (D), Q4.3 (D)

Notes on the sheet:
Switching frequency and sell count selection.
we go with 3k for: 1.5Mhz freq 1S battery
IMPORTANT

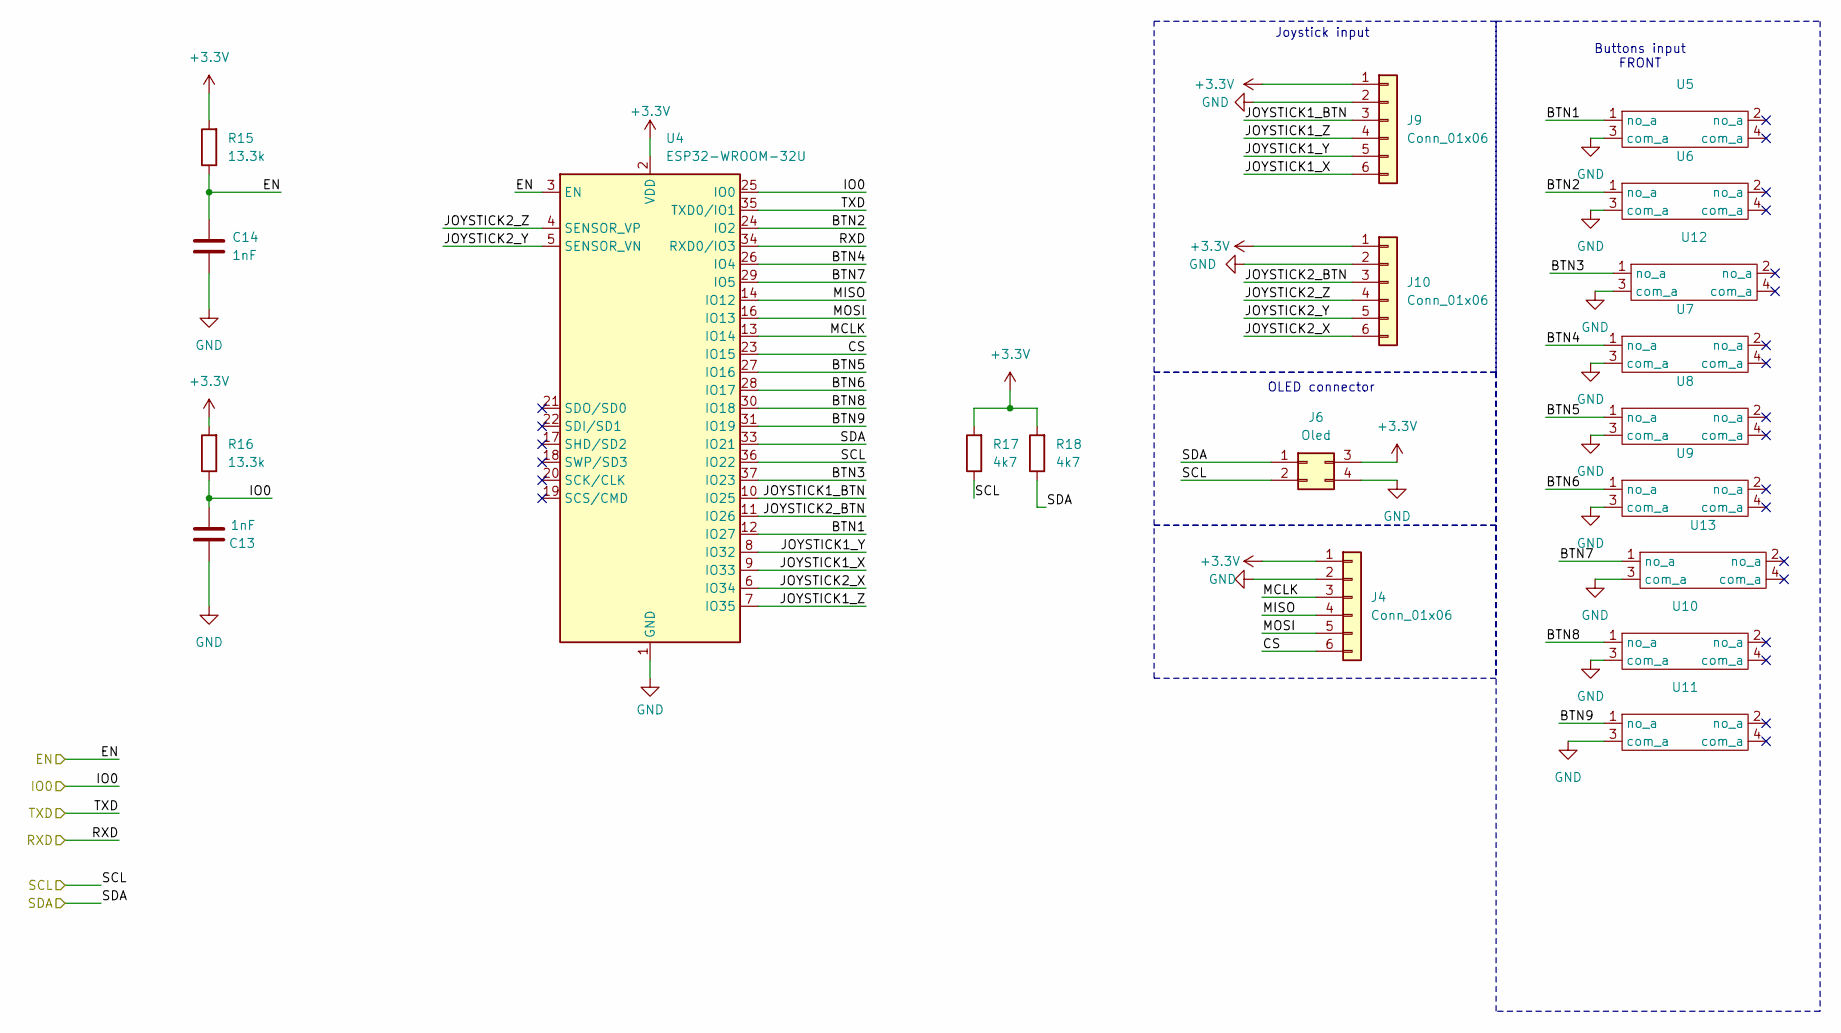
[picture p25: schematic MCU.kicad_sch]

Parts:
C13, C14: 1nF; C_0603_1608Metric; LCSC C1588
J4, J9, J10: Conn_01x06; JST_PH_B6B-PH-K_1x06_P2.00mm_Vertical
J6: Oled; PinSocket_2x02_P2.54mm_Vertical
R15, R16: 13.3k; R_0603_1608Metric; LCSC C25952
R17, R18: 4k7; R_0402_1005Metric; LCSC C25952
U4: ESP32-WROOM-32U
U5, U6, U7, U8, U9, U10, U11, U12, U13: ts-1212f

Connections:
+3.3V: J4.1, J6.3, J9.1, J10.1, R15.2, R16.2, R17.2, R18.2, U4.2 (VDD); also elsewhere on the board
/GPIO/SCL: J6.2, R17.1, U4.36 (IO22); also elsewhere on the board
/GPIO/SDA: J6.1, R18.1, U4.33 (IO21); also elsewhere on the board
/MCU/BTN1: U4.12 (IO27), U5.1 (no_a)
/MCU/BTN2: U4.24 (IO2), U6.1 (no_a)
/MCU/BTN3: U4.37 (IO23), U12.1 (no_a)
/MCU/BTN4: U4.26 (IO4), U7.1 (no_a)
/MCU/BTN5: U4.27 (IO16), U8.1 (no_a)
/MCU/BTN6: U4.28 (IO17), U9.1 (no_a)
/MCU/BTN7: U4.29 (IO5), U13.1 (no_a)
/MCU/BTN8: U4.30 (IO18), U10.1 (no_a)
/MCU/BTN9: U4.31 (IO19), U11.1 (no_a)
/MCU/CS: J4.6, U4.23 (IO15)
/MCU/EN: C14.1, R15.1, U4.3 (EN); also elsewhere on the board
/MCU/IO0: C13.2, R16.1, U4.25 (IO0); also elsewhere on the board
/MCU/JOYSTICK1_BTN: J9.3, U4.10 (IO25)
/MCU/JOYSTICK1_X: J9.6, U4.9 (IO33)
/MCU/JOYSTICK1_Y: J9.5, U4.8 (IO32)
/MCU/JOYSTICK1_Z: J9.4, U4.7 (IO35)
/MCU/JOYSTICK2_BTN: J10.3, U4.11 (IO26)
/MCU/JOYSTICK2_X: J10.6, U4.6 (IO34)
/MCU/JOYSTICK2_Y: J10.5, U4.5 (SENSOR_VN)
/MCU/JOYSTICK2_Z: J10.4, U4.4 (SENSOR_VP)
/MCU/MCLK: J4.3, U4.13 (IO14)
/MCU/MISO: J4.4, U4.14 (IO12)
/MCU/MOSI: J4.5, U4.16 (IO13)
/MCU/RXD: U4.34 (RXD0/IO3); also elsewhere on the board
/MCU/TXD: U4.35 (TXD0/IO1); also elsewhere on the board
GND: C13.1, C14.2, J4.2, J6.4, J9.2, J10.2, U4.1 (GND), U4.15 (GND), U4.38 (GND), U4.39 (GND), U5.3 (com_a), U6.3 (com_a), U7.3 (com_a), U8.3 (com_a), U9.3 (com_a), U10.3 (com_a), U11.3 (com_a), U12.3 (com_a), U13.3 (com_a); also elsewhere on the board

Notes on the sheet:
Buttons input FRONT
Joystick input
OLED connector

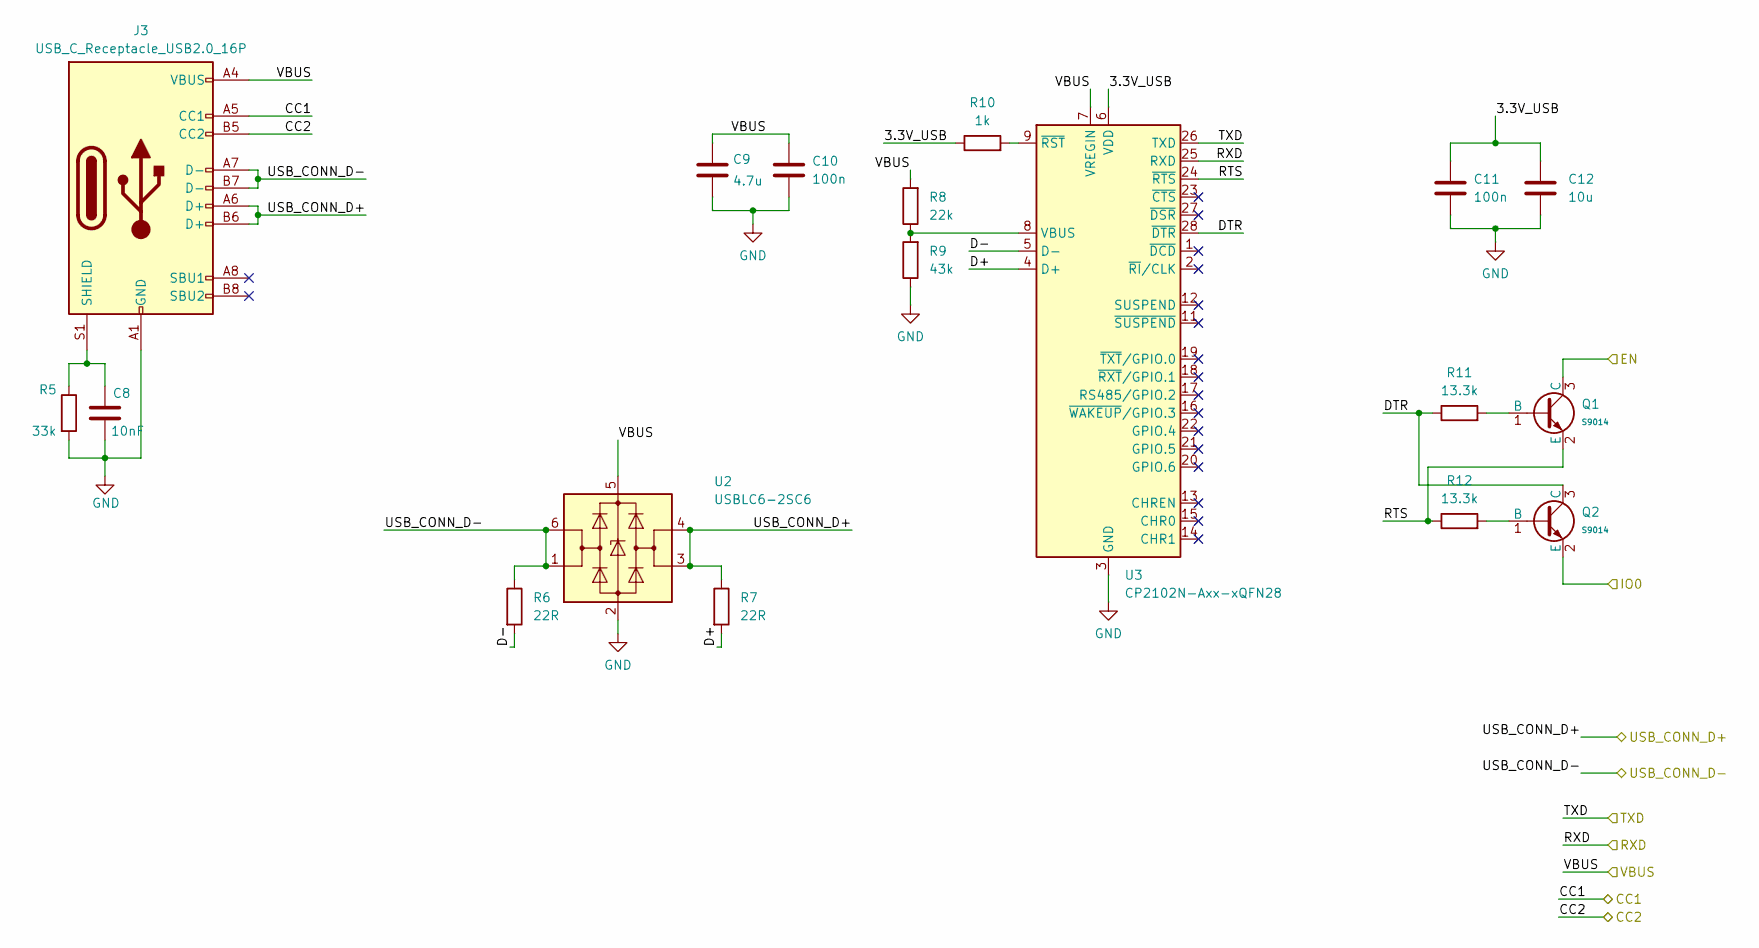
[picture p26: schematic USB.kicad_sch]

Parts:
C8: 10nF; R_0603_1608Metric; LCSC C57112
C9: 4.7u; R_0603_1608Metric; LCSC C19702
C10, C11: 100n; R_0603_1608Metric; LCSC C14663
C12: 10u; R_0603_1608Metric; LCSC C19702
J3: USB_C_Receptacle_USB2.0_16P; USB_C_Receptacle_HCTL_HC-TYPE-C-16P-01A; LCSC C2765186
Q1, Q2: S9014; Q_SOT-23; Part S9014; LCSC C20069130
R5: 33k; R_0603_1608Metric; LCSC C4216
R6, R7: 22R; R_0603_1608Metric; LCSC C71618
R8: 22k; R_0402_1005Metric; LCSC C25952
R9: 43k; R_0402_1005Metric; LCSC C25952
R10: 1k; R_0603_1608Metric; LCSC C14676
R11, R12: 13.3k; R_0603_1608Metric; LCSC C25952
U2: USBLC6-2SC6; SOT-23-6; LCSC C5180249
U3: CP2102N-Axx-xQFN28; QFN-28-1EP_5x5mm_P0.5mm_EP3.35x3.35mm; LCSC C964632

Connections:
/MCU/EN: Q1.3 (C); also elsewhere on the board
/MCU/IO0: Q2.2 (E); also elsewhere on the board
/MCU/RXD: U3.26 (TXD); also elsewhere on the board
/MCU/TXD: U3.25 (RXD); also elsewhere on the board
/PD/CC1: J3.A5 (CC1); also elsewhere on the board
/PD/CC2: J3.B5 (CC2); also elsewhere on the board
/PD/VBUS: C9.1, C10.1, J3.A4 (VBUS), J3.A9 (VBUS), J3.B4 (VBUS), J3.B9 (VBUS), R8.2, U2.5 (VBUS), U3.7 (VREGIN); also elsewhere on the board
/USB/3.3V_USB: C11.1, C12.1, R10.1, U3.6 (VDD)
/USB/D+: R7.2, U3.4 (D+)
/USB/D-: R6.2, U3.5 (D-)
/USB/DTR: Q2.3 (C), R11.1, U3.28 (~DTR)
/USB/RTS: Q1.2 (E), R12.1, U3.24 (~RTS)
/USB/USB_CONN_D+: J3.A6 (D+), J3.B6 (D+), R7.1, U2.3 (I/O2), U2.4 (I/O2)
/USB/USB_CONN_D-: J3.A7 (D-), J3.B7 (D-), R6.1, U2.1 (I/O1), U2.6 (I/O1)
GND: C8.2, C9.2, C10.2, C11.2, C12.2, J3.A1 (GND), J3.A12 (GND), J3.B1 (GND), J3.B12 (GND), R5.2, R9.1, U2.2 (GND), U3.3 (GND), U3.29 (GND); also elsewhere on the board
unnamed: C8.1, J3.S1 (SHIELD), R5.1
unnamed: Q1.1 (B), R11.2
unnamed: Q2.1 (B), R12.2
unnamed: R8.1, R9.2, U3.8 (VBUS)
unnamed: R10.2, U3.9 (~RST)

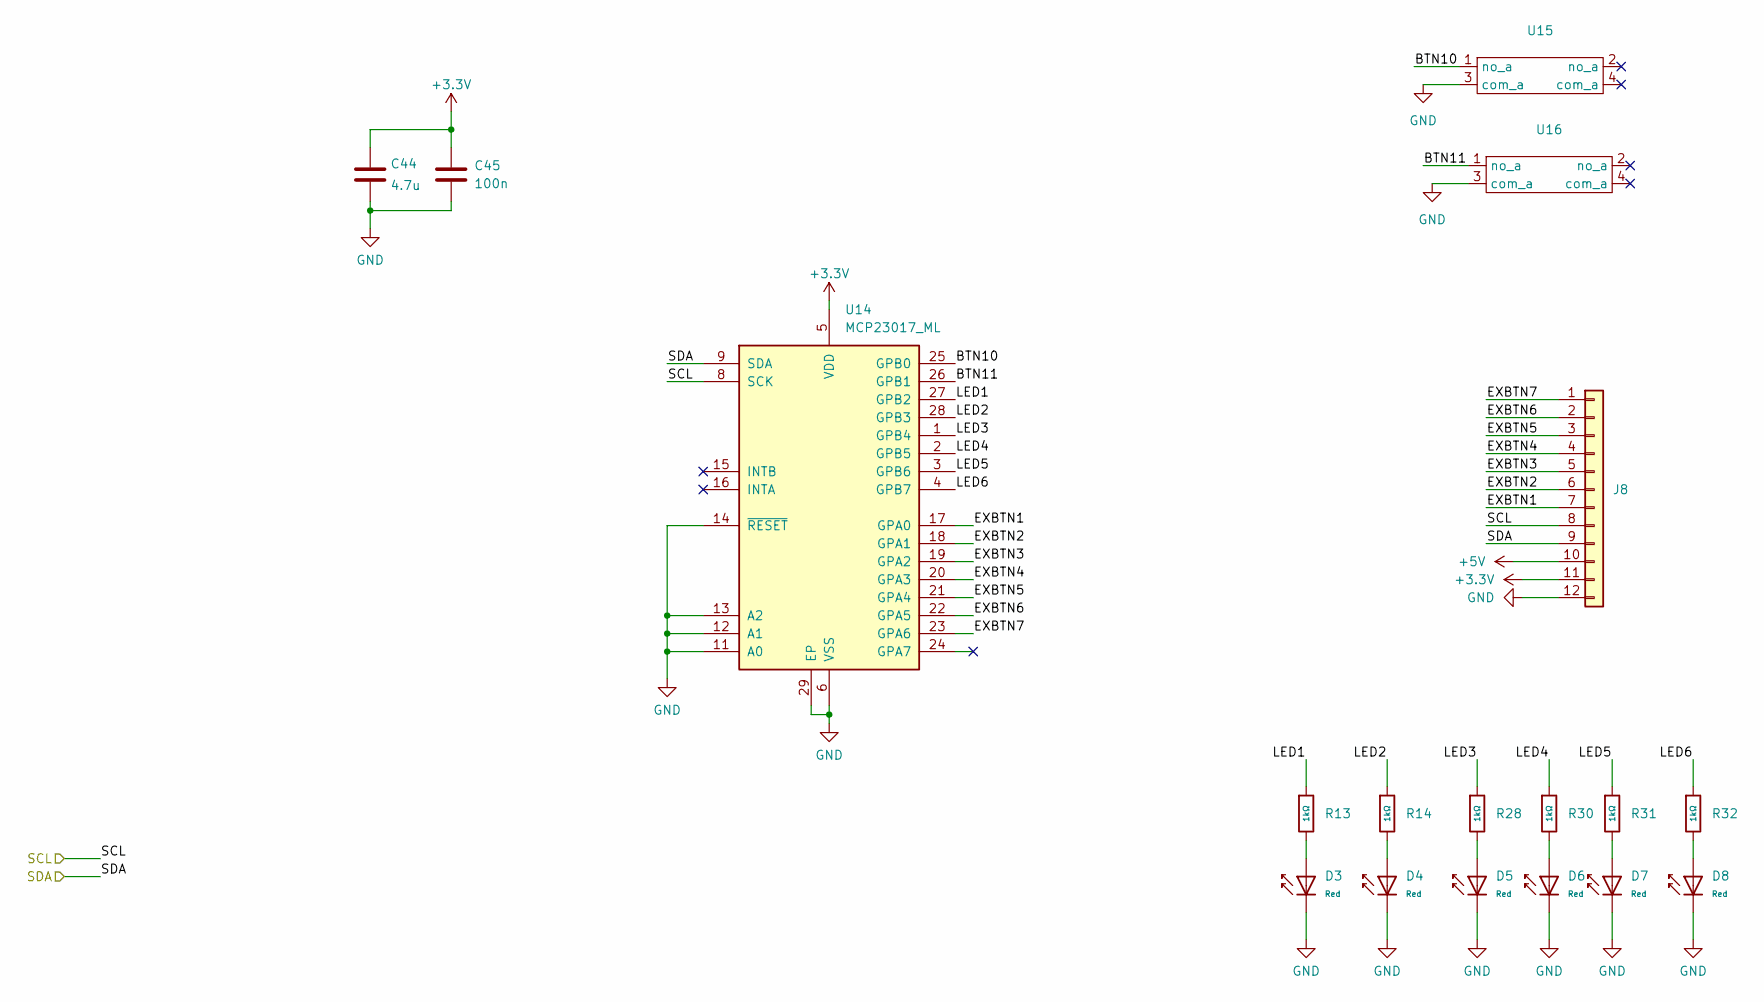
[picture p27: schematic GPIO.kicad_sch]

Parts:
C44: 4.7u; R_0603_1608Metric; LCSC C19702
C45: 100n; R_0603_1608Metric; LCSC C14663
D3, D4, D5, D6, D7, D8: Red; D_0603; Part KT-0603R; LCSC C2286
J8: Conn_01x12; JST_PH_B12B-PH-K_1x12_P2.00mm_Vertical
R13, R14, R28, R30, R31, R32: 1kΩ; R_0603; Overload Voltage (Max) 75V; Tolerance ±1%; Part 0603WAF1001T5E; LCSC C21190
U14: MCP23017_ML; QFN-28-1EP_6x6mm_P0.65mm_EP4.25x4.25mm
U15, U16: ts-1212f

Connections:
+3.3V: C44.1, C45.1, J8.11, U14.5 (VDD); also elsewhere on the board
+5V: J8.10; also elsewhere on the board
/GPIO/BTN10: U14.25 (GPB0), U15.1 (no_a)
/GPIO/BTN11: U14.26 (GPB1), U16.1 (no_a)
/GPIO/EXBTN1: J8.7, U14.17 (GPA0)
/GPIO/EXBTN2: J8.6, U14.18 (GPA1)
/GPIO/EXBTN3: J8.5, U14.19 (GPA2)
/GPIO/EXBTN4: J8.4, U14.20 (GPA3)
/GPIO/EXBTN5: J8.3, U14.21 (GPA4)
/GPIO/EXBTN6: J8.2, U14.22 (GPA5)
/GPIO/EXBTN7: J8.1, U14.23 (GPA6)
/GPIO/LED1: R13.1, U14.27 (GPB2)
/GPIO/LED2: R14.1, U14.28 (GPB3)
/GPIO/LED3: R28.1, U14.1 (GPB4)
/GPIO/LED4: R30.1, U14.2 (GPB5)
/GPIO/LED5: R31.1, U14.3 (GPB6)
/GPIO/LED6: R32.1, U14.4 (GPB7)
/GPIO/SCL: J8.8, U14.8 (SCK); also elsewhere on the board
/GPIO/SDA: J8.9, U14.9 (SDA); also elsewhere on the board
GND: C44.2, C45.2, D3.1, D4.1, D5.1, D6.1, D7.1, D8.1, J8.12, U14.6 (VSS), U14.11 (A0), U14.12 (A1), U14.13 (A2), U14.14 (~RESET), U14.29 (EP), U15.3 (com_a), U16.3 (com_a); also elsewhere on the board
unnamed: D3.2, R13.2
unnamed: D4.2, R14.2
unnamed: D5.2, R28.2
unnamed: D6.2, R30.2
unnamed: D7.2, R31.2
unnamed: D8.2, R32.2

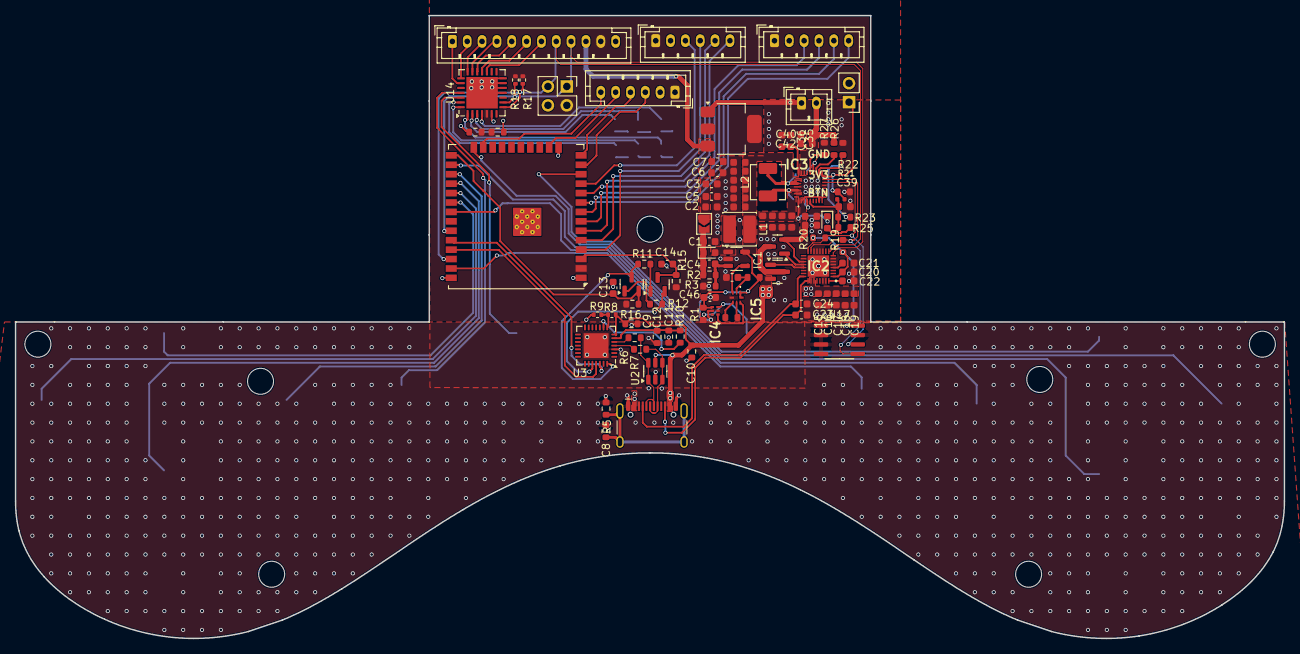
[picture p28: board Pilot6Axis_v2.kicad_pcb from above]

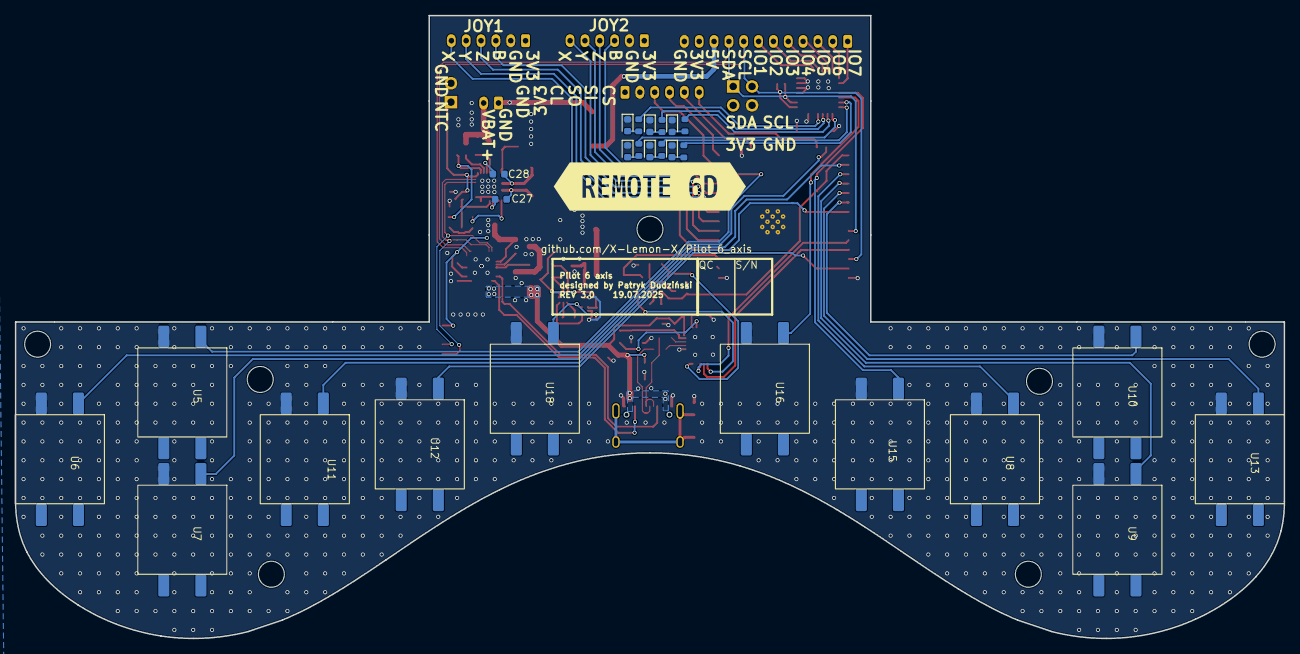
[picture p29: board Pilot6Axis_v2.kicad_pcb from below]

Board: 2 copper layers, 171.0 x 83.9 mm, 126 parts (27 on the bottom side), 99 nets.

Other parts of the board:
kibuzzard-6828A41A: G***; kibuzzard-6828A41A

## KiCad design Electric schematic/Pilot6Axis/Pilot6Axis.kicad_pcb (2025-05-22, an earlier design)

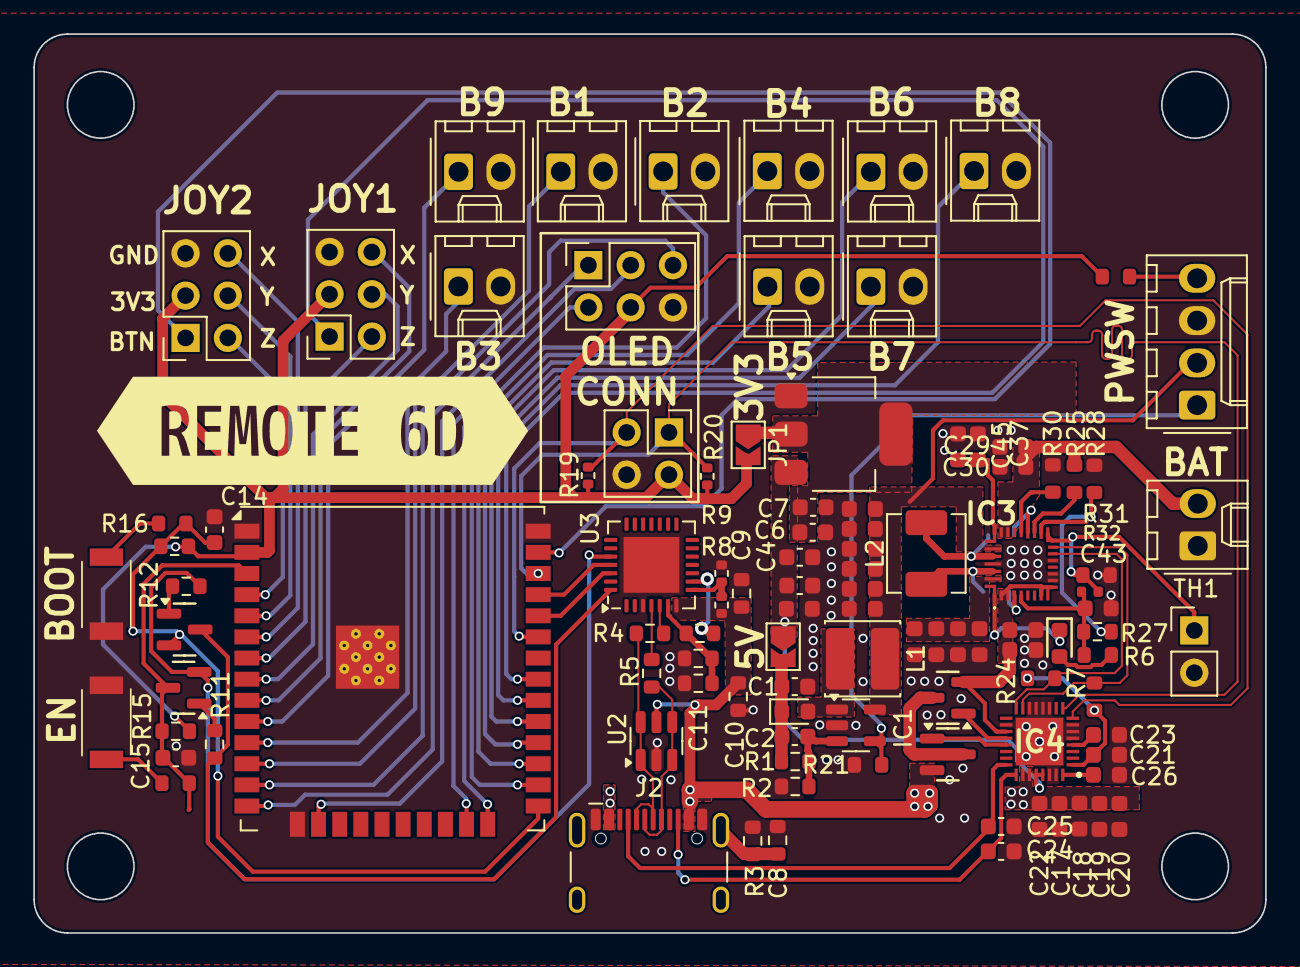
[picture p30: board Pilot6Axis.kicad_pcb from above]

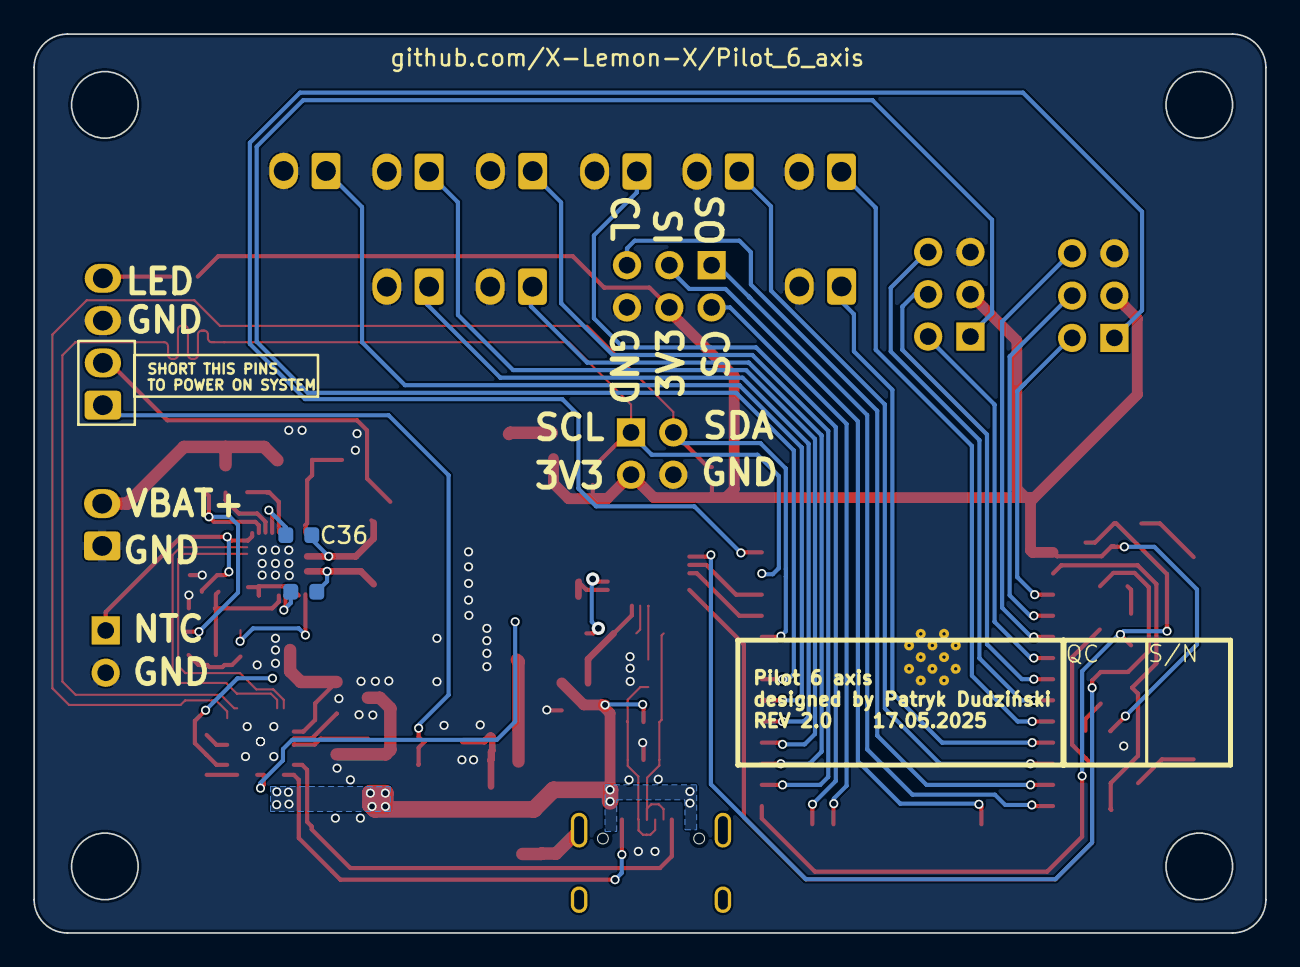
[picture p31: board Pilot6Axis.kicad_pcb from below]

Board: 2 copper layers, 74.0 x 54.0 mm, 107 parts (2 on the bottom side), 77 nets.

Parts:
C1: 4.7uF; C_0603_1608Metric
C2, C24, C25: 220pF; C_0603_1608Metric
C4, C7: 100nF; C_0603_1608Metric
C5, C6, C14, C15: 1nF; C_0603_1608Metric
C8: 10nF; R_0603_1608Metric
C9: 4.7u; R_0603_1608Metric
C10, C11: 100n; R_0603_1608Metric
C12: 10u; R_0603_1608Metric
C16, C21, C22, C23, C29, C30, C31, C32, C34, C38, C39, C40, C41, C42: 10uF; C_0603
C17, C43: 4.7uF; C_0603
C18, C19, C20, C26, C27, C28, C33, C44: 100nF; C_0603
C35, C36: 47nF; C_0603
C37, C45: 1nF; C_0603
D1: MBR0520; D_0603_1608Metric
D4: Red; D_0603
IC1: LM27313XMFX_NOPB; SOT-23-5
IC3: BQ25792RQMR
IC4: TPS25751SRSMR; QFN40P400X400X100-33N-D
J1: Battery input; Molex_KK-254_AE-6410-02A_1x02_P2.54mm_Vertical
J2: USB_C_Receptacle_USB2.0_16P; USB_C_Receptacle_HCTL_HC-TYPE-C-16P-01A
J3, J19: Conn_02x03_Odd_Even; PinSocket_2x03_P2.54mm_Vertical
J5: Oled; PinSocket_2x02_P2.54mm_Vertical
J6: BTN1; Molex_KK-254_AE-6410-02A_1x02_P2.54mm_Vertical
J7: BTN2; Molex_KK-254_AE-6410-02A_1x02_P2.54mm_Vertical
J8: BTN3; Molex_KK-254_AE-6410-02A_1x02_P2.54mm_Vertical
J9: BTN4; Molex_KK-254_AE-6410-02A_1x02_P2.54mm_Vertical
J10: BTN5; Molex_KK-254_AE-6410-02A_1x02_P2.54mm_Vertical
J11: BTN6; Molex_KK-254_AE-6410-02A_1x02_P2.54mm_Vertical
J12: BTN7; Molex_KK-254_AE-6410-02A_1x02_P2.54mm_Vertical
J13: BTN8; Molex_KK-254_AE-6410-02A_1x02_P2.54mm_Vertical
J14: BTN9; Molex_KK-254_AE-6410-02A_1x02_P2.54mm_Vertical
J15: Power switch; Molex_KK-254_AE-6410-04A_1x04_P2.54mm_Vertical
J16: Oled; PinSocket_2x03_P2.54mm_Vertical
JP1, JP300: SolderJumper_2_Bridged; SolderJumper-2_P1.3mm_Open_TrianglePad1.0x1.5mm
L1: 10uH; L_Cenker_CKCS4018
L2: 1u; L_APV_APH0420
Q1, Q3: S9014; Q_SOT-23
Q2, Q4: AO3400A; Q_SOT-23
R1: 40.5k; R_0603_1608Metric
R2, R11, R12, R15, R16: 13.3k; R_0603_1608Metric
R3: 33k; R_0603_1608Metric
R4, R5: 22R; R_0603_1608Metric
R6, R22: 1kΩ; R_0603
R7, R24: 4.7kΩ; R_0603
R8: 22k; R_0402_1005Metric
R9: 43k; R_0402_1005Metric
R10: 1k; R_0603_1608Metric
R13, R26: 22Ω; R_0603
R19, R20: 4k7; R_0402_1005Metric
R21: 10kΩ; R_0603
R25: 100Ω; R_0603
R27: 127k; R_0603_1608Metric
R28: 100kΩ; R_0603
R30: 3kΩ; R_0603
R31: 30kΩ; R_0603
R32: 5.1kΩ; R_0402
SW1, SW2: SW_Push; TS1088R02026
TH1: 10k; PinHeader_1x02_P2.54mm_Vertical
U1: AMS1117-3.3; SOT-223-3_TabPin2
U2: USBLC6-2SC6; SOT-23-6
U3: CP2102N-Axx-xQFN28; QFN-28-1EP_5x5mm_P0.5mm_EP3.35x3.35mm
U4: ESP32-WROOM-32U
kibuzzard-6828A41A: G***; kibuzzard-6828A41A

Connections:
+3.3V: J3.3, J5.3, J16.4, J19.3, JP1.2 (B), R15.2, R16.2, R19.2, R20.2, R22.1, U4.2 (VDD)
+5V: C4.1, C5.1, C16.1, IC4.28 (PP5V_1), IC4.29 (PP5V_2), JP300.1 (A), U1.3 (VI)
/BAT+: C29.1, C30.1, IC3.22 (BAT_1), IC3.23 (BAT_2), J1.2, R25.2
/MCU/BTN1: J6.1, U4.12 (IO27)
/MCU/BTN2: J7.1, U4.24 (IO2)
/MCU/BTN3: J8.1, U4.11 (IO26)
/MCU/BTN4: J9.1, U4.26 (IO4)
/MCU/BTN5: J10.1, U4.27 (IO16)
/MCU/BTN6: J11.1, U4.28 (IO17)
/MCU/BTN7: J12.1, U4.29 (IO5)
/MCU/BTN8: J13.1, U4.30 (IO18)
/MCU/BTN9: J14.1, U4.10 (IO25)
/MCU/CS: J16.2, U4.23 (IO15)
/MCU/EN: C15.1, Q3.3 (C), R13.2, R15.1, U4.3 (EN)
/MCU/IO0: C14.2, Q1.2 (E), R16.1, R26.2, U4.25 (IO0)
/MCU/JOYSTICK1_BTN: J19.1, U4.31 (IO19)
/MCU/JOYSTICK1_X: J19.6, U4.9 (IO33)
/MCU/JOYSTICK1_Y: J19.4, U4.8 (IO32)
/MCU/JOYSTICK1_Z: J19.2, U4.7 (IO35)
/MCU/JOYSTICK2_BTN: J3.1, U4.37 (IO23)
/MCU/JOYSTICK2_X: J3.6, U4.6 (IO34)
/MCU/JOYSTICK2_Y: J3.4, U4.5 (SENSOR_VN)
/MCU/JOYSTICK2_Z: J3.2, U4.4 (SENSOR_VP)
/MCU/MCLK: J16.5, U4.13 (IO14)
/MCU/MISO: J16.1, U4.14 (IO12)
/MCU/MOSI: J16.3, U4.16 (IO13)
/MCU/RXD: U3.26 (TXD), U4.34 (RXD0/IO3)
/MCU/SCL: IC4.9 (I2CT_SCL), J5.1, R20.1, U4.36 (IO22)
/MCU/SDA: IC4.8 (I2CT_SDA), J5.2, R19.1, U4.33 (IO21)
/MCU/TXD: U3.25 (RXD), U4.35 (TXD0/IO1)
/PD/BTST1: C35.2, IC3.4 (BTST1)
/PD/BTST2: C36.1, IC3.19 (BTST2)
/PD/CC1: C25.2, IC4.24 (CC1), J2.A5 (CC1)
/PD/CC2: C24.2, IC4.25 (CC2), J2.B5 (CC2)
/PD/CHARGER_VSYS: C27.1, C28.1, IC3.2 (VBUS_1), IC3.3 (VBUS_2), IC3.8 (VAC2), IC3.9 (VAC1_1), IC3.31 (VAC1_2), IC4.19 (VSYS), Q4.2 (S)
/PD/GATE_VBUS: IC4.21 (GATE_VBUS), Q2.1 (G)
/PD/GATE_VSYS: IC4.20 (GATE_VSYS), Q4.1 (G)
/PD/I2CC_SCL: IC3.14 (SCL), IC4.16 (I2CC_SCL), R24.2
/PD/I2CC_SDA: IC3.15 (SDA), IC4.15 (I2CC_SDA), R7.2
/PD/ILIM_HIZ: IC3.17 (ILIM_HIZ), R27.2, R28.1
/PD/LDO_1V5: C23.1, IC4.4 (LDO_1V5)
/PD/LDO_3V3: C21.1, IC4.1 (LDO_3V3), R7.1, R24.1
/PD/PMID: C31.1, C32.1, C33.1, C34.1, IC3.29 (PMID)
/PD/PROG: IC3.20 (PROG), R30.1
/PD/REGN: C43.1, IC3.5 (REGN), R6.1, R27.1, R32.1
/PD/SDRV_1: C37.1, C45.1, IC3.24 (SDRV_1), IC3.33 (SDRV_2)
/PD/STAT_1: D4.1, IC3.1 (STAT_1), IC3.30 (STAT_2)
/PD/SW1: C35.1, IC3.28 (SW1), L2.1
/PD/SW2: C36.2, IC3.26 (SW2), L2.2
/PD/TS_1: IC3.16 (TS_1), IC3.32 (TS_2), R31.1, R32.2, TH1.1
/PD/VBUS: C9.1, C10.1, C17.1, C18.1, C19.1, C20.1, C22.1, IC4.26 (VBUS_1), IC4.27 (VBUS_2), J2.A4 (VBUS), J2.A9 (VBUS), J2.B4 (VBUS), J2.B9 (VBUS), Q2.2 (S), R8.2, U2.5 (VBUS), U3.7 (VREGIN)
/PD/VCC_OUT: C38.1, C39.1, C40.1, C41.1, C42.1, C44.1, IC1.5 (VIN), IC3.25 (SYS), J15.2, L1.2
/PD/VIN_3V3: C26.1, IC4.32 (VIN_3V3)
/Power/+3V3_UNPROTEC: C6.1, C7.1, JP1.1 (A), U1.2 (VO)
/Power/+5V_UNPROTEC: C1.1, C2.2, D1.1 (K), JP300.2 (B), R1.1
/Power/BOOST_SW: D1.2 (A), IC1.1 (SW), L1.1
/Power/VPOWER_ENABLE: IC1.4 (~SHDN), J15.1, R21.1
/USB/3.3V_USB: C11.1, C12.1, R10.1, U3.6 (VDD)
/USB/D+: R5.2, U3.4 (D+)
/USB/D-: R4.2, U3.5 (D-)
/USB/DTR: Q1.3 (C), R11.1, U3.28 (~DTR)
/USB/RTS: Q3.2 (E), R12.1, U3.24 (~RTS)
/USB/USB_CONN_D+: J2.A6 (D+), J2.B6 (D+), R5.1, U2.3 (I/O2), U2.4 (I/O2)
/USB/USB_CONN_D-: J2.A7 (D-), J2.B7 (D-), R4.1, U2.1 (I/O1), U2.6 (I/O1)
GND: C1.2, C4.2, C5.2, C6.2, C7.2, C8.2, C9.2, C10.2, C11.2, C12.2, C14.1, C15.2, C16.2, C17.2, C18.2, C19.2, C20.2, C21.2, C22.2, C23.2, C24.1, C25.1, C26.2, C27.2, C28.2, C29.2, C30.2, C31.2, C32.2, C33.2, C34.2, C37.2, C38.2, C39.2, C40.2, C41.2, C42.2, C43.2, C44.2, C45.2, IC1.2 (GND), IC3.10 (ACDRV2), IC3.11 (ACDRV1), IC3.13 (~CE), IC3.27 (GND), IC4.5 (GPIO0), IC4.6 (GPIO1), IC4.7 (GPIO2), IC4.11 (GND_1), IC4.12 (GND_2), IC4.13 (GPIO11), IC4.14 (GND_3), IC4.18 (GPIO3), IC4.30 (GPIO7), IC4.31 (GPIO6), IC4.33 (GND_4), J1.1, J2.A1 (GND), J2.A12 (GND), J2.B1 (GND), J2.B12 (GND), J3.5, J5.4, J6.2, J7.2, J8.2, J9.2, J10.2, J11.2, J12.2, J13.2, J14.2, J15.3, J16.6, J19.5, R2.1, R3.2, R9.1, R21.2, R28.2, R30.2, R31.2, SW1.1, SW2.1, TH1.2, U1.1 (GND), U2.2 (GND), U3.3 (GND), U3.29 (GND), U4.1 (GND), U4.15 (GND), U4.38 (GND), U4.39 (GND)
unnamed: D4.2, R6.2
unnamed: C2.1, IC1.3 (FB), R1.2, R2.2
unnamed: IC3.18 (BATP), R25.1
unnamed: C8.1, J2.S1 (SHIELD), R3.1
unnamed: J15.4, R22.2
unnamed: Q1.1 (B), R12.2
unnamed: Q2.3 (D), Q4.3 (D)
unnamed: Q3.1 (B), R11.2
unnamed: R13.1, SW1.2
unnamed: R26.1, SW2.2
unnamed: R8.1, R9.2, U3.8 (VBUS)
unnamed: R10.2, U3.9 (~RST)

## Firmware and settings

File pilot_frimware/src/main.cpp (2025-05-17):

#include <Adafruit_GFX.h>
#include <Adafruit_SSD1306.h>
#include <Arduino.h>
#include <AsyncTCP.h>
#include <ESPAsyncWebServer.h>
// #include <WebServer.h>
#include <WiFi.h>
#include <WiFiClient.h>
#include <WiFiUdp.h>
#include <Wire.h>
#include <esp_wifi.h>

#include "esp32-hal-cpu.h"
#include <list>
#include <string>

#include "EPPROMSetings.h"
#include "IO_Control.h"
#include "OledPrintLib.h"
#include "PassGenerator.h"
#include "Setings.h"
#include "SetingsPage.h"
#include "PageGenerator.hpp"
#include "main.hpp"


// Display
Adafruit_SSD1306 display = Adafruit_SSD1306(SCREEN_WIDTH, SCREEN_HEIGHT, &Wire, OLED_RESET);
OledPrintLib *oledPrint  = NULL;
String displayLines[DISPLAY_MAX_LINE_COUNT];
int lineCount = 0;


uint8_t newMACAddress[] = { 0xA0, 0x46, 0x2A, 0x7A, 0x68, 0x36 }; // A0-46-2A-7A-68-36
IPAddress access_poin_ip(192, 168, 50, 1);
IPAddress access_poin_gateway(192, 168, 50, 1);
IPAddress access_poin_subnet(255, 255, 255, 0);

// HTTP server
AsyncWebServer server(80);


// IO
FourAxisJoystick joystick1;
FourAxisJoystick joystick2;
InputsData inputs_main;
uint8_t RC_Mode = RC_MODE_NORMAL;

RcSettings rc_settings = {};
EPPROM_Settings epprom_settings;
bool Wifi_Connected = false;
bool restart_flag   = false;

// https://microcontrollerslab.com/esp32-esp8266-web-server-input-data-html-forms/

void Task_ReadingInputs(void *param);
void Task_Conenct_to_Wifi(void *param);
void Task_SendUDP_data(void *param);

#pragma region Display

void Print(String string) {
#ifdef DEBUG
  Serial.print(string);
#endif
  oledPrint->Print(string);
}

void Println(String string) {
#ifdef DEBUG
  Serial.println(string);
#endif
  oledPrint->Println(string);
}

void UpdateLine(String string) {
  oledPrint->UpdateLine(string);
}

void UpdateLine(String string, int line) {
  oledPrint->UpdateLine(string, line);
}

#pragma endregion

void PrintSetings(RcSettings setings) {
  Serial.println("Setings:");
  Serial.println("ver:");
  Serial.println("");
  Serial.println("");

  Serial.println("Left Joystick Min:");
  Serial.println(String(setings.int_Joystick_left_MMin));
  Serial.println("Left Joystick Max:");
  Serial.println(String(setings.int_Joystick_left_MMax));
  Serial.println("Right Joystick Min:");
  Serial.println(String(setings.int_Joystick_right_MMin));
  Serial.println("Right Joystick Max:");
  Serial.println(String(setings.int_Joystick_right_MMax));
  Serial.println("Left Joystick Filter:");
  Serial.println(String(setings.flo_Joystick_left_filer));
  Serial.println("Right Joystick Filter:");
  Serial.println(String(setings.flo_Joystick_right_filer));
  Serial.println("Update Freq:");
  Serial.println(String(setings.int_upd_freq));
  Serial.println("Host Port:");
  Serial.println(String(setings.int_host_port));
  Serial.println("SSID:");
  Serial.println(String(setings.str_ssid));
  Serial.println("Password:");
  Serial.println(String(setings.str_passwd));
  Serial.println("Target IP:");
  Serial.println(String(setings.str_target_ip));
  for(int i = 0; i < WIFI_NETWORKS_MAX; ++i) {
    Serial.println("WiFi Seed[" + String(i) + "]:");
    Serial.println(String(setings.str_wifi_ssids[i]));
    Serial.println("WiFi Password[" + String(i) + "]:");
    Serial.println(String(setings.str_wifi_passwords[i]));
  }
}

void PrintInfo() {
  Println("Remote Controler 6D");
  Println("ver: " + String(VERSION));
}

void LoadSetings() {


  // we load some default values to the settings
  rc_settings.int_Joystick_left_MMin   = -2048;
  rc_settings.int_Joystick_left_MMax   = 2048;
  rc_settings.int_Joystick_right_MMin  = -2048;
  rc_settings.int_Joystick_right_MMax  = 2048;
  rc_settings.flo_Joystick_left_filer  = 0.95f;
  rc_settings.flo_Joystick_right_filer = 0.95f;
  rc_settings.int_upd_freq             = 20;
  rc_settings.int_host_port            = 25000;
  strcpy(rc_settings.str_ssid, "RC_6D");
  strcpy(rc_settings.str_passwd, "qwerty1234");
  strcpy(rc_settings.str_target_ip, "192.168.20.2");
  // str_target_ip
  // str_host_wifi
  strcpy(rc_settings.str_wifi_ssids[0], "NomadT");
  strcpy(rc_settings.str_wifi_passwords[0], "NomadToliwka");

  epprom_settings.init(sizeof(rc_settings));
#ifdef SAVE_TO_FLASH
  epprom_settings.save_settings(rc_settings, SETTINGS_ADRES_BEG);
#endif
  epprom_settings.load_settings(rc_settings, SETTINGS_ADRES_BEG);
}

void GPIOinit() {
  pinMode(PIN_MS_BTN_1, INPUT_PULLUP);
  pinMode(PIN_MS_BTN_2, INPUT_PULLUP);
  pinMode(PIN_MS_BTN_3, INPUT_PULLUP);
  pinMode(PIN_MS_BTN_4, INPUT_PULLUP);
  pinMode(PIN_MS_BTN_5, INPUT_PULLUP);
  pinMode(PIN_MS_BTN_6, INPUT_PULLUP);
  pinMode(PIN_MS_BTN_7, INPUT_PULLUP);
  pinMode(PIN_MS_BTN_8, INPUT_PULLUP);

  pinMode(PIN_BTN_JOYSTIK_1, INPUT_PULLUP);
  pinMode(PIN_BTN_JOYSTIK_2, INPUT_PULLUP);

  pinMode(PIN_X_ROT_JOYSTIK_1, INPUT);
  pinMode(PIN_Y_ROT_JOYSTIK_1, INPUT);
  pinMode(PIN_Z_ROT_JOYSTIK_1, INPUT);

  pinMode(PIN_X_ROT_JOYSTIK_2, INPUT);
  pinMode(PIN_Y_ROT_JOYSTIK_2, INPUT);
  pinMode(PIN_Z_ROT_JOYSTIK_2, INPUT);

  joystick1.init(RESOLUTION_12_BIT, PIN_X_ROT_JOYSTIK_1, PIN_Y_ROT_JOYSTIK_1, PIN_Z_ROT_JOYSTIK_1,
                 PIN_BTN_JOYSTIK_1, rc_settings.flo_Joystick_left_filer, rc_settings.int_Joystick_left_MMin,
                 rc_settings.int_Joystick_left_MMax);

  joystick2.init(RESOLUTION_12_BIT, PIN_X_ROT_JOYSTIK_2, PIN_Y_ROT_JOYSTIK_2, PIN_Z_ROT_JOYSTIK_2,
                 PIN_BTN_JOYSTIK_2, rc_settings.flo_Joystick_right_filer, rc_settings.int_Joystick_right_MMin,
                 rc_settings.int_Joystick_right_MMax);

  joystick1.AutoZero();
  joystick2.AutoZero();
}

void DisplayInit() {
  if(!display.begin(SSD1306_SWITCHCAPVCC, SCREEN_ADDRESS)) {
    Serial.println(F("SSD1306 allocation failed"));
    for(;;)
      ;
  }
  display.display();
  display.clearDisplay();
  display.setTextSize(1);
  display.setTextColor(SSD1306_WHITE);
  display.display();
  Serial.println("SSD1306 allocation success");
  oledPrint = new OledPrintLib(&display, DISPLAY_MAX_LINE_COUNT, DISPLAY_MAX_CHARACTER_COUNT);
}

#pragma region WEB PAGES

void PageNotFound(AsyncWebServerRequest *request) {
  request->send(404, "text/plain", "Not found");
}

void InitAccessPoint() {

#ifdef DEBUG
  Serial.println("wifi setup sd:");
  Serial.println(rc_settings.str_ssid);
  Serial.println("wifi setup pw:");
  Serial.println(rc_settings.str_passwd);
#endif

  WiFi.mode(WIFI_AP);
  // WiFi.softAPConfig(apIP, gateway, subnet);
  WiFi.softAPConfig(access_poin_ip, access_poin_gateway, access_poin_subnet);
  WiFi.softAP(rc_settings.str_ssid, rc_settings.str_passwd);
}

void InitAllWebEvents() {
  server.on("/", HTTP_GET, [](AsyncWebServerRequest *request) {
    auto page = PageGenerator::generate_page(rc_settings);
    request->send_P(200, "text/html", page.c_str());
  });

  server.on("/get", HTTP_GET, [](AsyncWebServerRequest *request) {
    RcSettings temp_settings = rc_settings;
    auto info                = PageGenerator::get_settings_from_page(request, temp_settings);
    auto page                = PageGenerator::get_saved_settings_page(info);
    request->send(200, "text/html", page.c_str());
    if(info) {
      epprom_settings.save_settings(temp_settings, SETTINGS_ADRES_BEG);
      restart_flag = true;
      Println("Settings saved!");
    }
  });

  server.onNotFound(PageNotFound);
  server.begin();
}

#pragma endregion

int look_for_saved_seed(String ssid) {
  for(int i = 0; i < WIFI_NETWORKS_MAX; i++) {
    if(strcmp(rc_settings.str_wifi_ssids[i], ssid.c_str()) == 0)
      return i;
  }
  return -1;
}

bool ConnectWithWifiNetwork() {
  WiFi.mode(WIFI_STA);
  esp_wifi_set_mac(WIFI_IF_STA, &newMACAddress[0]);
  WiFi.disconnect();
  bool not_connected = true;
  std::vector<int> ssids;
  WiFi.scanNetworks();
  vTaskDelay(1000);

  while(not_connected) {
    Println("Scanning for WiFi...");
    int i = WiFi.scanNetworks();
    // if there are no networks we wait and try again
    if(i <= 0) {
      vTaskDelay(500);
      continue;
    }

    ssids.clear();
    for(int count = 0; count < i; count++) {
      String ssid = WiFi.SSID(count);
      Println("?:" + ssid);
      int maybe_seed = look_for_saved_seed(ssid);
      if(maybe_seed >= 0) {
        ssids.push_back(maybe_seed);
      }
    }

    // we sort the ssids to have the highest priority first
    std::sort(ssids.begin(), ssids.end());

    // we try to connect to the highest priority ssid
    for(auto &&seed : ssids) {
      WiFi.begin(rc_settings.str_wifi_ssids[seed], rc_settings.str_wifi_passwords[seed]);
      int connection_try_count = 0;
      Println("Connecting to:");
      Println("");
      delay(500);
      while(WiFi.status() != WL_CONNECTED && WIFI_CONNECTION_TRY_MAX_COUNT != connection_try_count++) {
        Print(".");
        delay(500);
      }

      if(WiFi.status() == WL_CONNECTED) {
        Println(rc_settings.str_wifi_ssids[seed]);
        Println("TIP:");
        Print(rc_settings.str_target_ip);
        Println("Port:");
        Print(String(rc_settings.int_host_port));
        Println("IP:");
        Print(WiFi.localIP().toString());
        not_connected = false;
        break;
      }
    }
  }
  return !not_connected;
}

void WaitForConnection() {
  wl_status_t statusPrev = WL_IDLE_STATUS;
  while(true) {
    wl_status_t status = WiFi.status();
    vTaskDelay(100);
    if(status != WL_CONNECTED) {
      Println("WIFI disconnected!");
      Wifi_Connected = ConnectWithWifiNetwork();
    }
    if(status == statusPrev)
      continue;
    if(Wifi_Connected)
      InitAllWebEvents();
    statusPrev = WiFi.status();
  }
}

void InitSetupMode() {
  InitAccessPoint();
  InitAllWebEvents();
  Println("--Setup mode--");
  Println("http://" + WiFi.softAPIP().toString());
  Println("sd:");
  Println(String(rc_settings.str_ssid));
  Println("pw:");
  Println(String(rc_settings.str_passwd));
}

void InitNormalMode() {
  xTaskCreate(Task_ReadingInputs, "Tread", 2000, NULL, 3, NULL);
  xTaskCreate(Task_Conenct_to_Wifi, "Twifi", 3000, NULL, 3, NULL);
  xTaskCreate(Task_SendUDP_data, "Tudp", 3000, NULL, 3, NULL);
}

void setup() {
  Serial.begin(115200);
  DisplayInit();
  PrintInfo();
  LoadSetings();
  PrintSetings(rc_settings);
  GPIOinit();

  if(!InOut::ReadInput(PIN_MS_BTN_4) || !InOut::ReadInput(PIN_MS_BTN_5)) {
    RC_Mode = RC_MODE_SETUP;
    InitSetupMode();
  } else {
    RC_Mode = RC_MODE_NORMAL;
    InitNormalMode();
  }
}

void loop() {

  if(restart_flag) {
    restart_flag = false;
    vTaskDelay(WAIT_TIME_BETWEEN_RESTART);
    ESP.restart();
  }
  vTaskDelay(100);
}

String fixString(int value, int size) {
  String str = String(value);
  if(str.length() >= size)
    return str;
  std::string adons = "";
  adons.resize(size - str.length(), ' ');
  return String(adons.c_str()) + str;
}

void Task_SendUDP_data(void *param) {
  WiFiUDP udp;
  IPAddress remoteIP;
  remoteIP.fromString(rc_settings.str_target_ip);

  unsigned int remotePort = rc_settings.int_host_port;
  float send_delay        = 1000.0 / (float)rc_settings.int_upd_freq;

  while(1) {
    String data = UDP_BEGIN + fixString(inputs_main.joystick_1_x, 5) + ":" + fixString(inputs_main.joystick_1_y, 5) +
                  ":" + fixString(inputs_main.joystick_1_z, 5) + ":" + fixString(inputs_main.joystick_1_btn, 1) +
                  ":" + fixString(inputs_main.joystick_2_x, 5) + ":" + fixString(inputs_main.joystick_2_y, 5) +
                  ":" + fixString(inputs_main.joystick_2_z, 5) + ":" + fixString(inputs_main.joystick_2_btn, 1) +
                  ":" + fixString(inputs_main.btn_1, 1) + ":" + fixString(inputs_main.btn_2, 1) + ":" +
                  fixString(inputs_main.btn_3, 1) + ":" + fixString(inputs_main.btn_4, 1) + ":" +
                  fixString(inputs_main.btn_5, 1) + ":" + fixString(inputs_main.btn_6, 1) + ":" +
                  fixString(inputs_main.btn_7, 1) + ":" + fixString(inputs_main.btn_8, 1) + ":" + UDP_END;

    if(Wifi_Connected) {
      udp.beginPacket(remoteIP, remotePort);
      udp.print(data);
      udp.endPacket();
    }
    vTaskDelay(pdMS_TO_TICKS(send_delay));
  }
}

void Task_Conenct_to_Wifi(void *param) {
  WaitForConnection();
}

void Task_ReadingInputs(void *param) {
  InputsData inputs;

  while(1) {
    inputs.joystick_1_x   = joystick1.readX();
    inputs.joystick_1_y   = joystick1.readY();
    inputs.joystick_1_z   = joystick1.readZ();
    inputs.joystick_1_btn = !joystick1.readBtn();

    inputs.joystick_2_x   = joystick2.readX();
    inputs.joystick_2_y   = joystick2.readY();
    inputs.joystick_2_z   = joystick2.readZ();
    inputs.joystick_2_btn = !joystick2.readBtn();

    inputs.btn_1 = !InOut::ReadInput(PIN_MS_BTN_1);
    inputs.btn_2 = !InOut::ReadInput(PIN_MS_BTN_2);
    inputs.btn_3 = !InOut::ReadInput(PIN_MS_BTN_3);
    inputs.btn_4 = !InOut::ReadInput(PIN_MS_BTN_4);
    inputs.btn_5 = !InOut::ReadInput(PIN_MS_BTN_5);
    inputs.btn_6 = !InOut::ReadInput(PIN_MS_BTN_6);
    inputs.btn_7 = !InOut::ReadInput(PIN_MS_BTN_7);
    inputs.btn_8 = !InOut::ReadInput(PIN_MS_BTN_8);
    inputs_main  = inputs;
    vTaskDelay(5);
  }
}

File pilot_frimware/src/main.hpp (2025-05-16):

#pragma once

// #include <EEPROM.h>   // https://randomnerdtutorials.com/esp32-flash-memory/
// #include <Preferences.h>  //
// https://randomnerdtutorials.com/esp32-save-data-permanently-preferences/

// for use of dual cores refere to
// https://randomnerdtutorials.com/esp32-dual-core-arduino-ide/

//----------------------IMPORTANT----BUILDING
// only use once to save new setings to flash -> Flush
// #define SAVE_TO_FLASH
// ESP32 with it uncomented then Flush again without it //newer work with it
// uncommented or it will break EPPROM
#define DEBUG

//-----------------------------INFO
#define VERSION 3.1

//-----------------------------JOYSTICKS PINOUT
#define PIN_X_ROT_JOYSTIK_1 33
#define PIN_Y_ROT_JOYSTIK_1 32
#define PIN_Z_ROT_JOYSTIK_1 35

#define PIN_X_ROT_JOYSTIK_2 34
#define PIN_Y_ROT_JOYSTIK_2 39
#define PIN_Z_ROT_JOYSTIK_2 36

#define PIN_BTN_JOYSTIK_1 19
#define PIN_BTN_JOYSTIK_2 23

//-----------------------------BTNs PINOUT
#define PIN_MS_BTN_1 15
#define PIN_MS_BTN_2 2
#define PIN_MS_BTN_3 0
#define PIN_MS_BTN_4 4
#define PIN_MS_BTN_5 16
#define PIN_MS_BTN_6 17
#define PIN_MS_BTN_7 5
#define PIN_MS_BTN_8 18

//-----------------------------ADDITIONAL PINOUT
#define PIN_BATTERY_VOLTAGE

//--------------WIFIpasssword.c_str()---------------OLED DISPLAY
#define SCREEN_WIDTH 128 // OLED display width, in pixels
#define SCREEN_HEIGHT 64 // OLED display height, in pixels
#define SCREEN_ADDRESS 0x3C
#define WIRE Wire
#define OLED_RESET -1 // 4

#define DISPLAY_MAX_LINE_COUNT 7
#define DISPLAY_MAX_CHARACTER_COUNT 22


//-----------------------------WIFI_SETUP
// #define WIFI_SETINGS_BEG_NAME "str_WIFI_"
#define WIFI_CONNECTION_TRY_MAX_COUNT 20


//-----------------------------UDP
#define UDP_BEGIN "$RC:"
#define UDP_END "#\r"
#define UDP_FIXED_SIZE 5


//-----------------------------SETINGS
#define RC_MODE_NORMAL 0
#define RC_MODE_SETUP 1


#define SETTINGS_ADRES_BEG 0

#define WAIT_TIME_BETWEEN_RESTART 2000

#define STRING_SIZE 35
#define WIFI_NETWORKS_MAX 10


struct InputsData {
  int joystick_1_x   = 0;
  int joystick_1_y   = 0;
  int joystick_1_z   = 0;
  int joystick_1_btn = 0;

  int joystick_2_x   = 0;
  int joystick_2_y   = 0;
  int joystick_2_z   = 0;
  int joystick_2_btn = 0;

  int btn_1 = 0;
  int btn_2 = 0;
  int btn_3 = 0;
  int btn_4 = 0;
  int btn_5 = 0;
  int btn_6 = 0;
  int btn_7 = 0;
  int btn_8 = 0;
};


struct RcSettings {
  int int_Joystick_left_MMin;
  int int_Joystick_left_MMax;
  int int_Joystick_right_MMin;
  int int_Joystick_right_MMax;

  float flo_Joystick_left_filer;
  float flo_Joystick_right_filer;

  int int_host_port;
  int int_upd_freq;
  char str_ssid[STRING_SIZE];
  char str_target_ip[STRING_SIZE];
  char str_passwd[STRING_SIZE];

  char str_wifi_ssids[WIFI_NETWORKS_MAX][STRING_SIZE];
  char str_wifi_passwords[WIFI_NETWORKS_MAX][STRING_SIZE];
};

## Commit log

2022-12-29 small fixes to Jyostick class adding web server with acces point early stage
    [FourAxisJoystick.cpp, main.cpp]
2023-01-01 added wifi all config saving in EEPROM wifi menaging setup websiet auto ceonnection to availabel networks samll loop error fixed
    [main.cpp]
2023-12-29 fixed issues, moved all to freeRtos wifi send is working, added python reciver
    [FourAxisJoystick.cpp, main.cpp]
2023-12-30 added descritpion list aprt iamges, updated readme
    [Pilot6axis-TopCover.3mf, Pilot6axis-botom.3mf]
2023-12-30 added schematics
    [pilot_6axis_electronic.kicad_pcb, pilot_6axis_electronic.kicad_sch]
2023-12-31 made small changes ti folder system
    [Pilot6axis-TopCover.3mf, Pilot6axis-botom.3mf]
2024-01-12 fixed missing t from settings verrb
    [main.cpp]
2024-02-07 fixed ros and added filtering and stuff
    [main.cpp]
2024-02-11 added stl files
    [Pilot6axisV2.step, TopCover.step]
2024-02-11 added new 3mf files
    [Pilot6axis-TopCover.3mf, Pilot6axis-botom.3mf, Pilot6axisV2.3mf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]
2024-02-13 added keyboard pilot fixed some issues in pilot
    [FourAxisJoystick.cpp, main.cpp]
2024-02-22 changed button 8 to space for dead man switch
2024-06-10 added new publisher for gripper
2024-06-17 fixed issue with wifi conencting 2 times insteda of one, code optimized, added acces point config
    [main.cpp]
2025-02-09 added pcb files
    [Pilot6Axis.kicad_pcb, Pilot6Axis.kicad_sch]
2025-02-19 Update pilot PCB versin 1.0
    [BMS.kicad_sch, BOM-Pilot6Axis.csv, CHARGER.kicad_sch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]
2025-02-21 added rev number and projekct info
    [Pilot6Axis-CuBottom.gbr, Pilot6Axis-CuTop.gbr, Pilot6Axis-EdgeCuts.gbr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]
2025-05-15 update schematic to kicajd 9.0, fixed usb D=/D- wrongly inerconnected , otherwise pcb seems to be woekring
    [CHARGER.kicad_sch, MCU.kicad_sch, Pilot6Axis.kicad_pcb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]
2025-05-16 [firmware] upgrade firmware do be l;ess diabolic,, fixed problew witf slow conenction of witfi, upgrade websie UI
    [FourAxisJoystick.cpp, main.cpp]
2025-05-16 added boom file
    [BOM-Pilot6Axis.ods]
2025-05-17 upgrade board to use USB BD for power delivery and addded SPI screen conector
    [BOM-Pilot6Axis.csv, BQ25792RQMR.stp, MCU.kicad_sch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]
2025-05-20 [pcb] cleanup schematics, made power trace slightl less intterfiring with usb
    [Pilot6Axis-CuBottom.gbr, Pilot6Axis-CuTop.gbr, Pilot6Axis-EdgeCuts.gbr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]
2025-05-22 [pd] added 5V to PD
    [CPL-Pilot6Axis.csv, Pilot6Axis-CuBottom.gbr, Pilot6Axis-CuTop.gbr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]
2025-05-22 fixed leyout
    [BOM-Pilot6Axis.csv, MCU.kicad_sch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]
2025-05-22 added gerber files
    [Pilot6Axis-CuBottom.gbr, Pilot6Axis-CuTop.gbr, Pilot6Axis-EdgeCuts.gbr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]
2025-06-14 update gerber
    [Pilot6Axis-CuBottom.gbr, Pilot6Axis-CuTop.gbr, Pilot6Axis-EdgeCuts.gbr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]
2025-07-19 [Pilot V2] PCB Rev 3.0| PD, WIFI| extendable IO| embeded switches, new conenctors, extenstion conenctors, new ON/OFF circuit
    [BMS.kicad_sch, BOM-Pilot6Axis.csv, BOM-Pilot6Axis.ods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]
2025-07-19 Removed unnecesary files
    [BOM-Pilot6Axis.csv, BOM-Pilot6Axis.ods, BOM-Pilot6Axis_v2.csv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]
2025-07-24 [pcb] added eeprom to pd charger so the ciofnig is remembered and set correctly
    [BOM-Pilot6Axis_v2.csv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]
